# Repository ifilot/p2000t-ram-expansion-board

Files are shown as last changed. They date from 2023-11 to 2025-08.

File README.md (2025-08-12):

# P2000T RAM expansion board







## Table of contents

* [Purpose](#purpose)
* [Memory lay-out](#memory-lay-out)
* [Installation](#installation)
* [Testing the expansion board](#testing-the-expansion-board)
* [Schematic](#schematic)
* [Bill of materials](#bill-of-materials)
* [Testing bank switching in BASIC](#testing-bank-switching-in-basic)
* [Files](#files)
* [Alternative RAM expansions](#alternative-ram-expansions)
  * [SMD-128KiB version](#smd-128kib-version)
  * [SMD-CPLD-128KiB version](#smd-cpld-128kib-version)
  * [SMD-CPLD-512KiB version](#smd-cpld-512kib-version)
  * [THT-1056 KiB expansion](#tht-1056-kib-expansion)
  * [THT-2080 KiB expansion](#tht-2080-kib-expansion)
* [License](#license)

> [!TIP] 
> Have questions or comments about the **P2000T RAM expansion**? Join
> the conversation and chat with the developers on our [Discord
> server](https://discord.gg/YtzJTWYAxy).

## Purpose

This repository provides several RAM expansion boards for the Philips P2000T,
ranging from 64 KiB to over 2 MiB. Options vary in complexity (THT, SMD, CPLD),
so choose a board that fits your soldering skills and tools. A RAM tester
utility is included to verify proper installation and functionality after
assembly.

> [!IMPORTANT]
> This repository includes various RAM expansion PCBs for the P2000T. Your
> choice should depend on your soldering skills (THT or SMD) and available
> tools (e.g. CPLD programmer). Review this README to find a board that
> matches your comfort level before starting a build. 

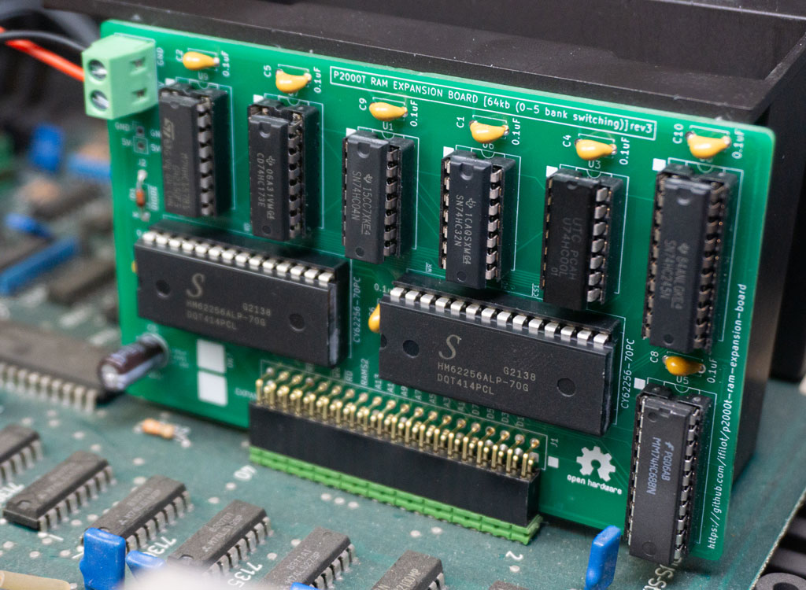
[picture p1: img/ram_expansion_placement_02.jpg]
ram expansion board


## Memory lay-out

The memory lay-out of the P2000T is organized as shown in the table below

| Address | Description |
| --- | --- |
| 0x0000-0x1000 | Monitor rom |
| 0x1000-0x4FFF | Cartridge |
| 0x5000-0x5FFF | Video memory |
| 0x6000-0x9FFF | RAM memory |
| 0xA000-0xDFFF | 16 KiB expansion |
| 0xE000-0xFFFF | 8 KiB banks |

For the default 16 KiB stock model, only the memory at `0x6000-0x9FFF` is
available. The most simple expansion board adds 64k memory such that an
additional 16 KiB of RAM is available at `0xA000-0xDFFF` and another 48 KiB
using bank switching. Bank switching means that you can only access 8 KiB of the
48 KiB at a time, depending on the value of a register which can be accessed via
an `OUT` instruction at `0x94`. This register can hold values of `0-5`,
amounting to 6x8 KiB = 48 KiB of bankable memory.

## Installation

To install the expansion board, you need to plug in the expansion board on the
corresponding expansion 2x20 male pin header on the male board. This pin header
is found directly behind the cartridge slots. Furthermore, you need to solder
a GND and a 5V line onto the power PCB (see image below) and insert that in the
screw terminal of the expansion board.

> [!WARNING]  
> Please check carefully that the polarity is correct. Although the board comes
> with reverse polarity protection in the form of a diode, it is always better
> to check twice before turning on the power.

In the image below, you see a GND (black) and a 5V (red) line attached to the
power PCB. Please ensure you solder the lines to the correct pins and check
with a multimeter before connecting to the RAM expansion board.

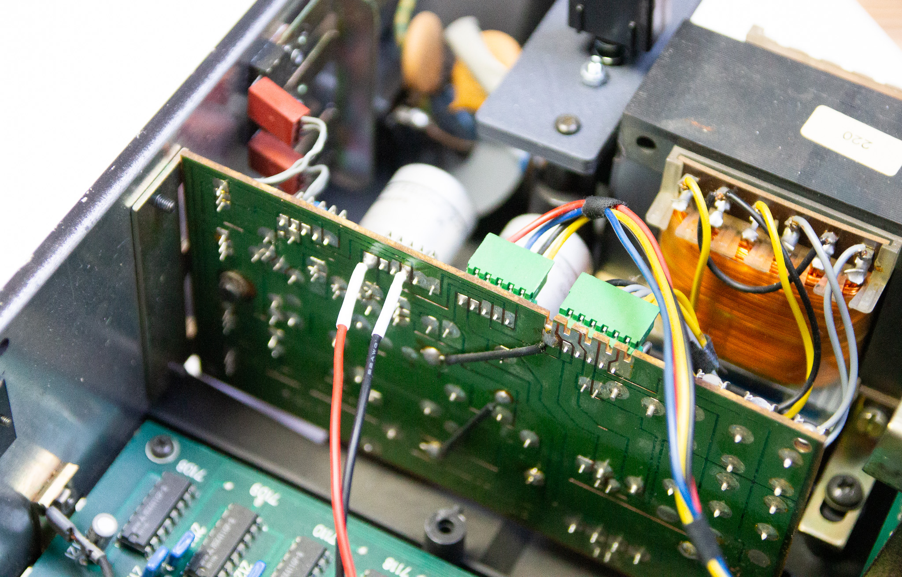
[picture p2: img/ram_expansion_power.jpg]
attaching GND and 5V wire to power PCB


Consult the image below for the correct voltages between the pins.

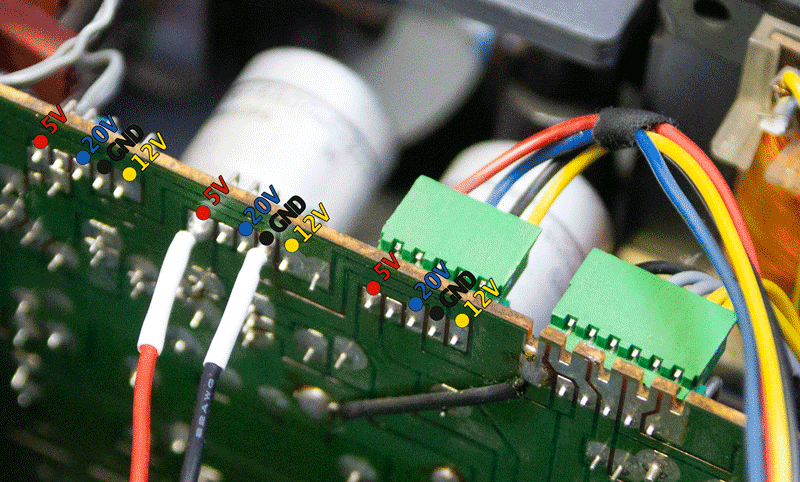
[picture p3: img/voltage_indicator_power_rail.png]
voltages on the power PCB


> [!WARNING]  
> Please check with a multimeter that you did not short-circuit any of the power
> lines on the POWER PCB. Please check this at least two times before turning on
> your P2000T. Short-circuiting of any of the power rails can cause permanent
> damage your machine.

## Testing the expansion board

This repository comes bundled with a RAM testing utility. Write the RAM testing
utility to a SLOT1 cartridge and boot your P2000T with this program in SLOT1.
The RAM testing utility will perform an extensive test of the memory and show
any errors it encounters.

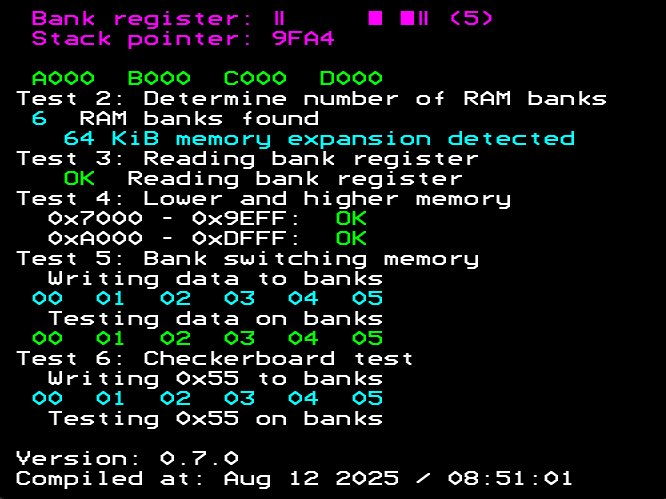
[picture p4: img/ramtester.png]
completed RAM test


## Schematic

The schematic for the RAM expansion board is shown below. The ram expansion
board essentially hosts two 32 KiB RAM chips and a bank register. Using a small
set of additional logic chips, the line decoding and bank switching is handled.

voltages on the power PCB

## Bill of materials

* 1x74HC00 (quad NAND-gate)
* 1x74HC04 (hex inverter)
* 1x74HC32 (quad OR-gate)
* 1x74HC157 (quad 2-input multiplexer)
* 1x74HC173 (quad positive edge triggered D-type flip-flop)
* 1x74HC688 (8-bit magnitude comparator)
* 1x74HC245 (octal bus transceiver)
* 2x62256 (32 KiB SRAM)
* 1x220uF capacitor (100uF also works)
* 8x0.1uF capacitor
* 1x1N4148 diode
* 1x 40 pin female pin header (2x20 pins; 2.54mm spacing)
* 1x screw terminal

**Unpopulated PCB**

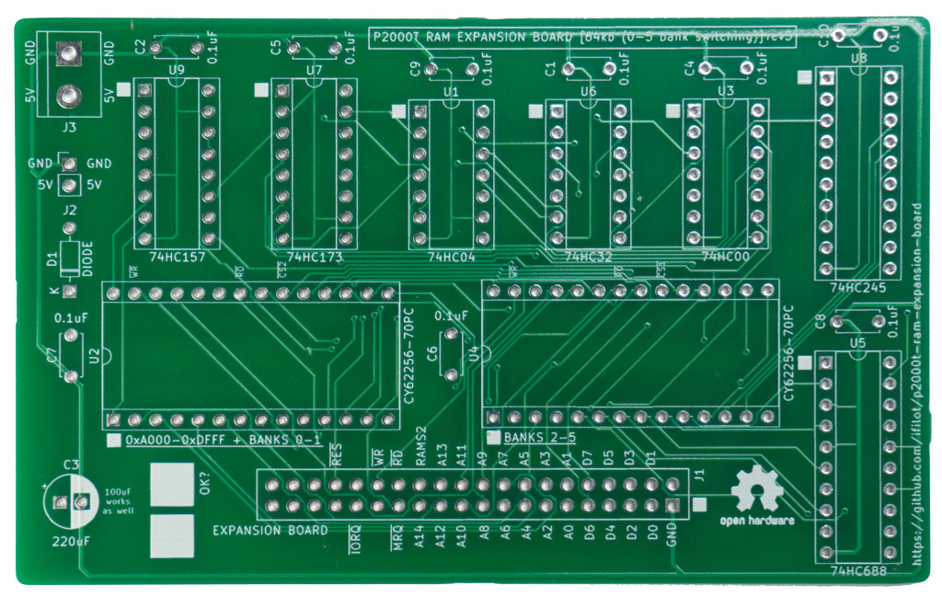
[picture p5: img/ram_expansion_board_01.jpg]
Unpopulated RAM board


**Populated PCB**

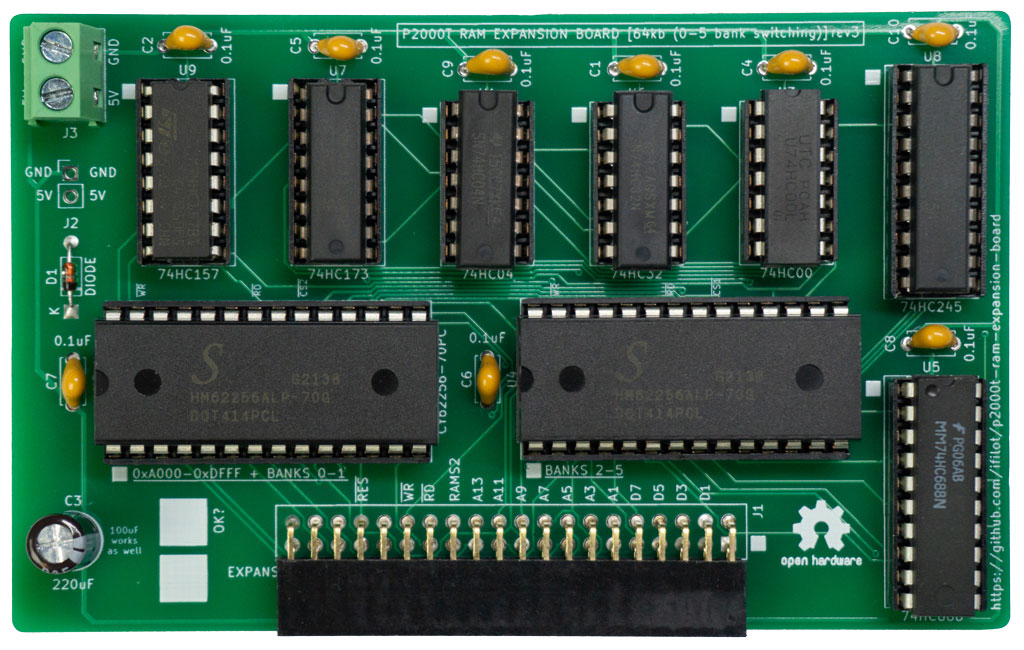
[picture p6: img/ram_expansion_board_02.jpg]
Populated RAM board


## Testing bank switching in BASIC

If you want to test the bank switching functionality in BASIC, you can use
the following instructions after booting the machine.

First, we need to set the top of BASIC to `0x9000`.

```
CLEAR 50,&H9000
```

The reason we do this is to ensure that the stack is not residing at the top 8
KiB because those bytes will become inaccessible after bank switching. Next, we
will first write a value to memory address `0xE000`, check that this value is
properly written, change to another bank and read from the same memory address.
A different value should be returned (typically 0). Next, we write a different
value to the `0xE000` and change bank to the initial bank. The original value
should now be correctly retrieved. The procedure is performed using the
following (very small) snippet of BASIC code.

```
10 POKE &HE000,42
20 PRINT(PEEK(&HE000))
30 OUT &H94,1
40 PRINT(PEEK(&HE000))
50 POKE &HE000,43
60 OUT &H94,0
70 PRINT(PEEK(&HE000))
```
After entering in these instructions, type `RUN`. The output of this code should
be something similar to the code as shown below. The second value might be
potentially different, depending on earlier memory operations, though is
expected to be a zero on a fresh boot of the machine.

```
42
0
42
```

## Files

* [KiCad schematics](pcb/p2000t-ram-expansion-board)
* [RAM tester utility](ramtester)

## Alternative RAM expansions

### SMD-128KiB version

Next to the 64 KiB memory expansion using
[DIP](https://en.wikipedia.org/wiki/Dual_in-line_package) chips, there is also a
128 KiB memory expansion using
[SMD](https://en.wikipedia.org/wiki/Surface-mount_technology) chips. Because of
the typical lower price of this last category of chips, this memory expansion is
a bit cheaper to produce. It does require you to be proficient in soldering on
SMD components.

The 128 KiB memory expansion uses a single `CY62128ELL-45SX` 128 KiB memory
chip. The lower 16 KiB of this chip can be accessed at `0xA000-0xDFFF`. The
remaining 112 KiB are available as 14 banks of 8 KiB each at `0xE000-0xFFFF`.
Similar to the other memory expansion boards, bank switching proceeds by writing
a value to I/O port `0x94`. One can also read back the current bank from this
port.

The source files for this board can be found
[here](pcb/p2000t-ram-expansion-board-128kb-smd/).

**Unpopulated PCB**

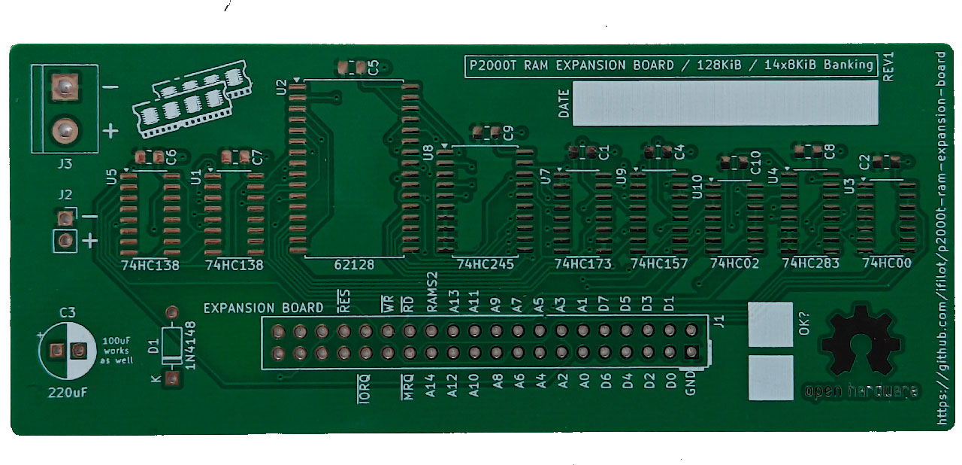
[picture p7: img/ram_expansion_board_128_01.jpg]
Unpopulated RAM board


**Populated PCB**

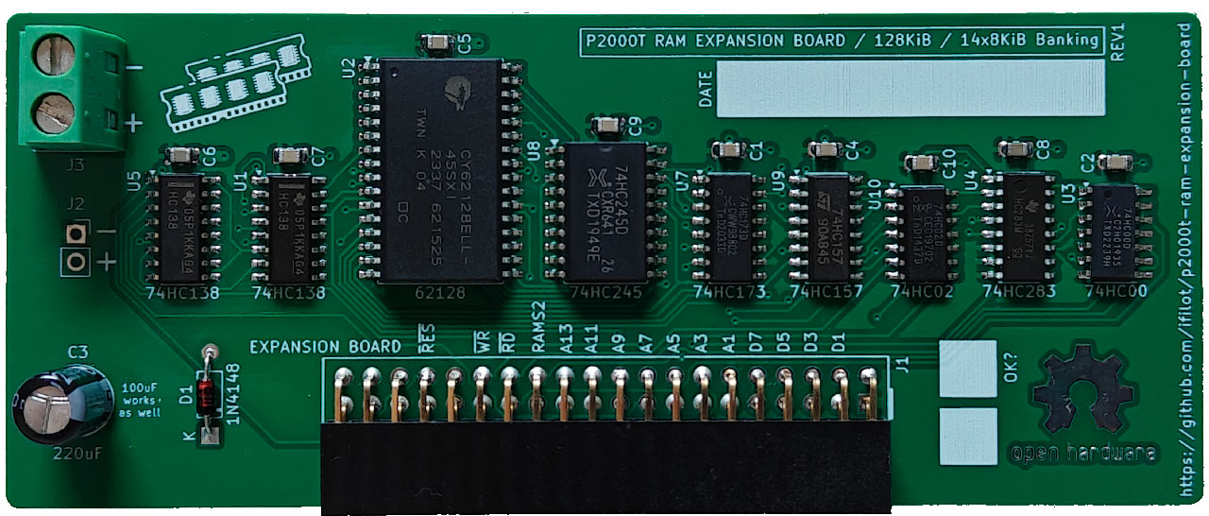
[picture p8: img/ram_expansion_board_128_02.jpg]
Populated RAM board


**Installed PCB**

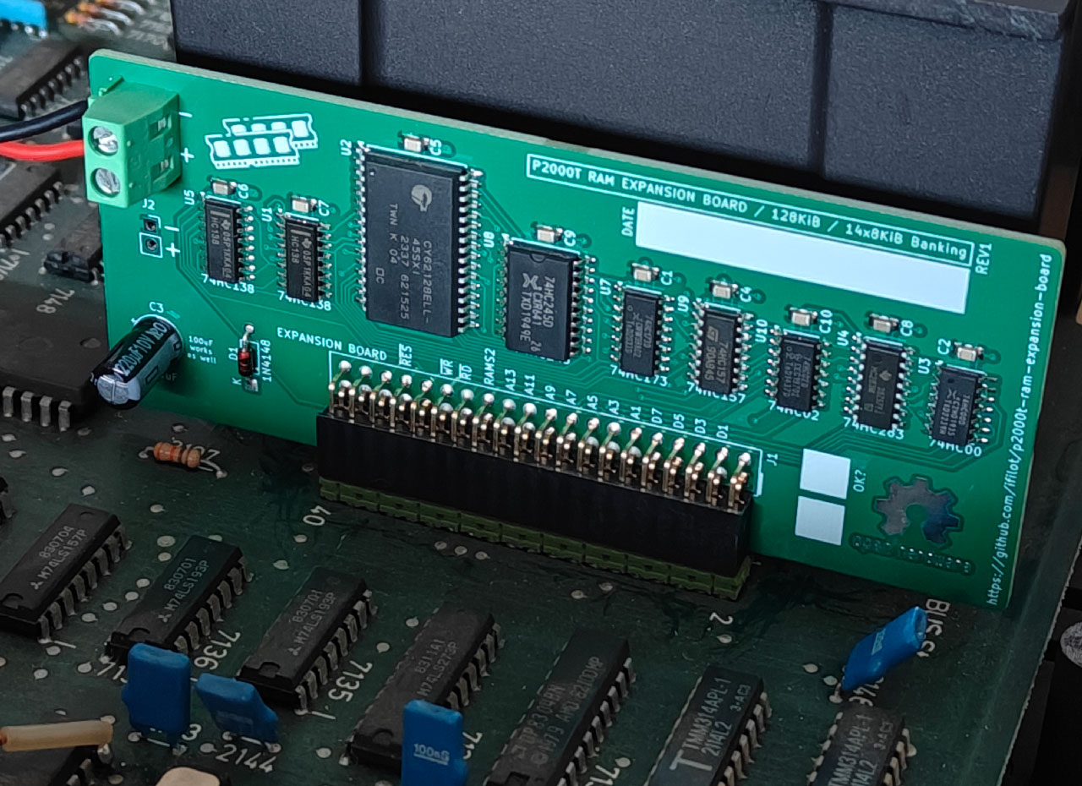
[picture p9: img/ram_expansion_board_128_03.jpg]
Installed 1056 KiB RAM board


### SMD-CPLD-128KiB version

To cut down costs even further, there is also a CUPL version. Besides the
`CY62128ELL-45SX`, the PCB only hosts one other chip: a `ATF1502`. All glue
logic required for the RAM expansion board is basically programmed on this chip.

The source files for this board can be found
[here](pcb/p2000t-ram-expansion-board-128-512-smd-cpld).

**Unpopulated PCB**

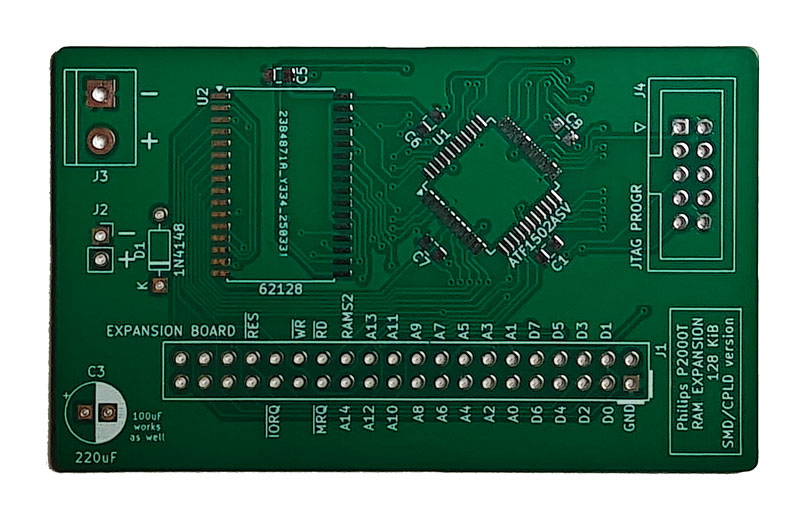
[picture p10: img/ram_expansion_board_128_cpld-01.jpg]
Unpopulated RAM board


**Populated PCB**

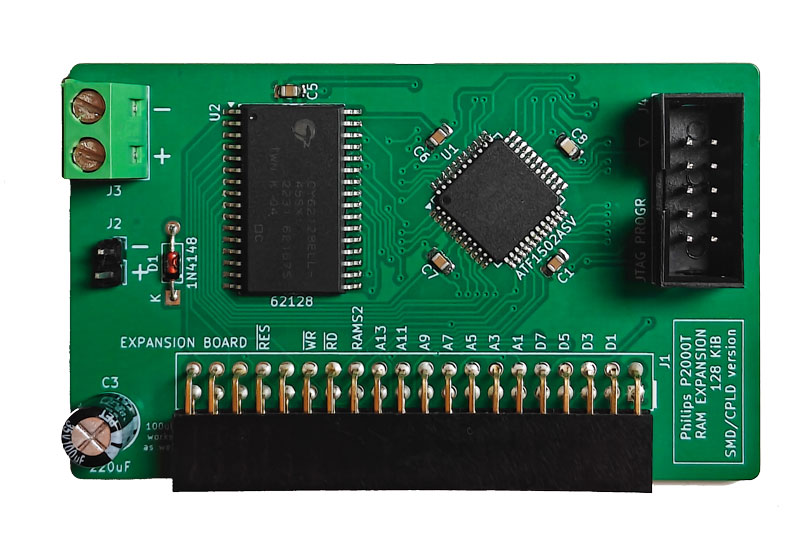
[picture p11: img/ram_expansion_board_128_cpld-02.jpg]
Populated RAM board


### SMD-CPLD-512KiB version

Moving beyond the 128 KiB limit, there is also a versatile SMD-type board
that admits 1-4 `CY62128ELL-45SX` 128 KiB memory chips.

The source files for this board can be found
[here](pcb/p2000t-ram-expansion-board-128-512-smd-cpld).

**Installed PCB**

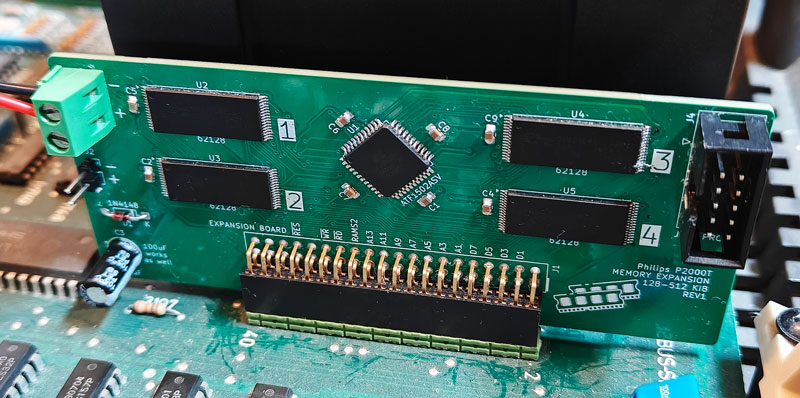
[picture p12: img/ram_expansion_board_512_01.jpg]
Installed RAM board


**Populated PCB**

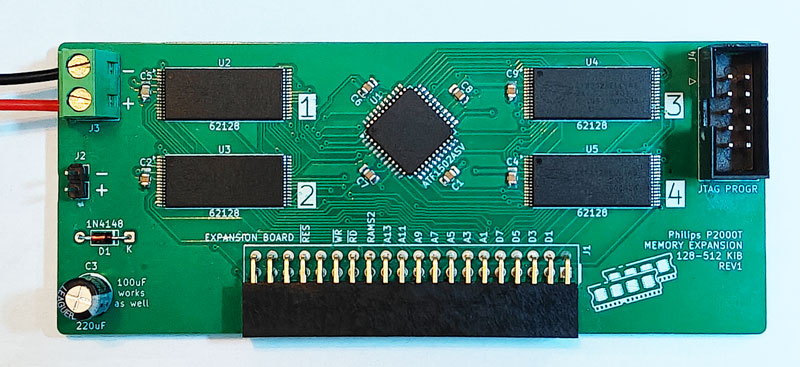
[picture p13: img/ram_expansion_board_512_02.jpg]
Populated RAM board


### THT-1056 KiB expansion

This board uses a single 32 KiB static RAM chip to provide 2x16 KiB on
`0xA000-0xDFFF` and two 512 KiB static RAM chips to provide another 128x8 KiB on
`0xE000-0xFFFF`. The way this board works is very similar to the regular 64 KiB
board. The highest bit in the bank register toggle the 16 KiB banking while the
lower 7 bits provide the banking for the 8 KiB of memory.

The source files for this board can be found
[here](pcb/p2000t-ram-expansion-board-1056kb/).

**Unpopulated PCB**

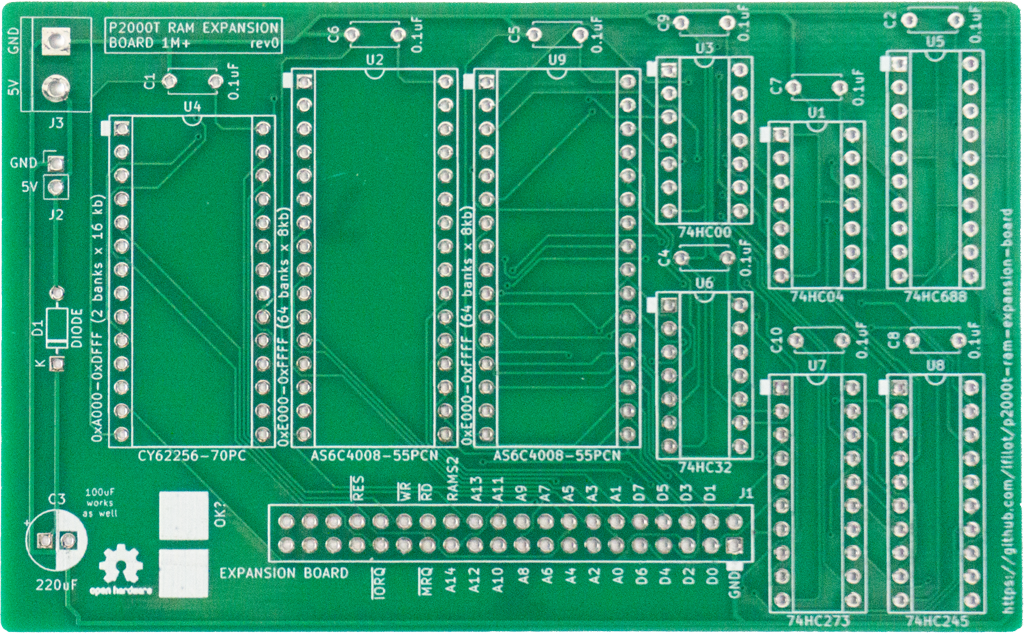
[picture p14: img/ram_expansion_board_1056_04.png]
Unpopulated RAM board


**Populated PCB**

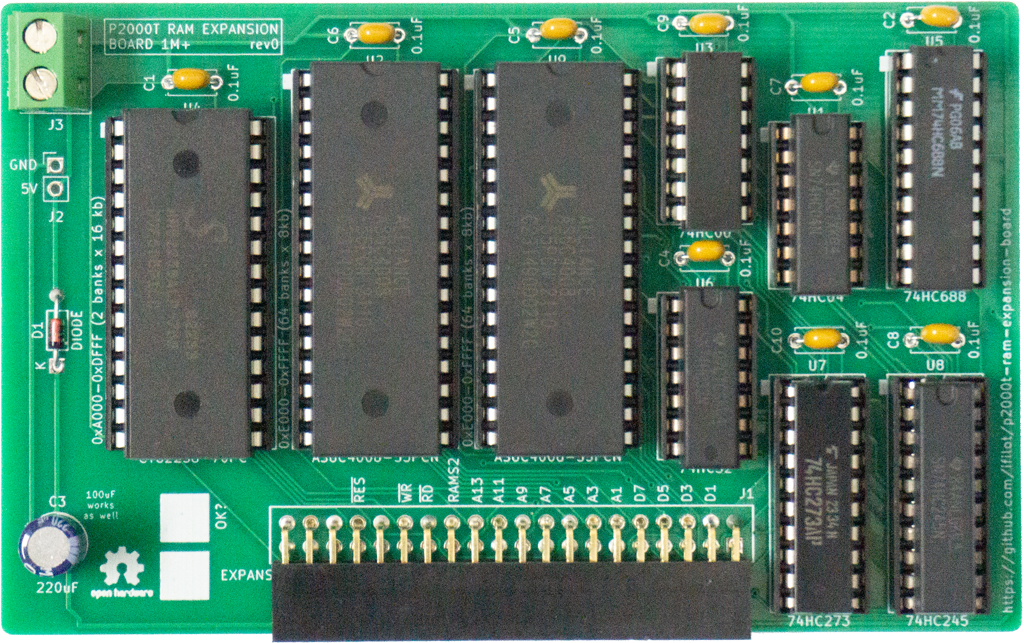
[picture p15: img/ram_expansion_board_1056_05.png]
Populated RAM board


**Installed PCB**

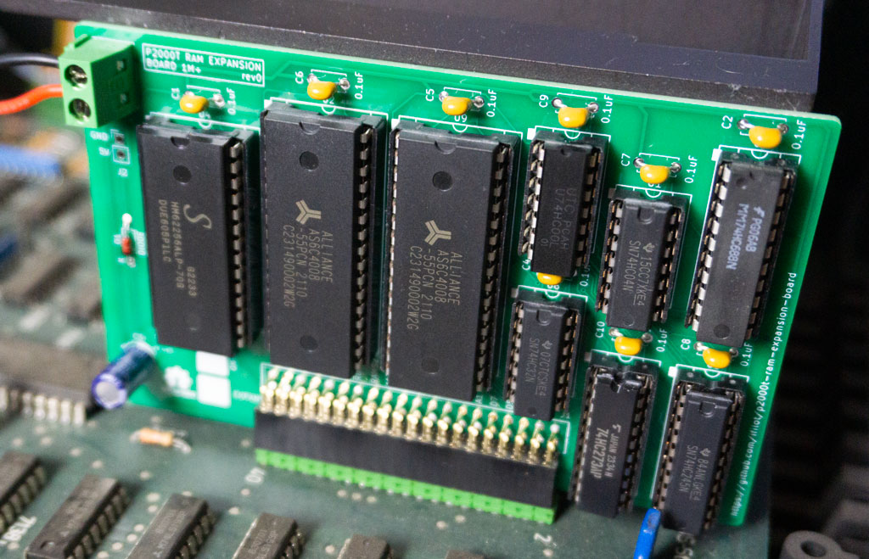
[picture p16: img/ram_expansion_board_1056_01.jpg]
Installed 1056 KiB RAM board


### THT-2080 KiB expansion

This board uses a single 32 KiB static RAM chip to provide 2x16 KiB on
`0xA000-0xDFFF` and four 512 KiB static RAM chips to provide another 256x8 KiB
on `0xE000-0xFFFF`. This board requires two bank registers, one 8-bit bank
register exposed on I/O port `0x94` and another two-bit bank register on I/O
port `0x95` (only one bit of the two-bit bank register is used).

The source files for this board can be found
[here](pcb/p2000t-ram-expansion-board-2080kb/).

**Populated PCB**

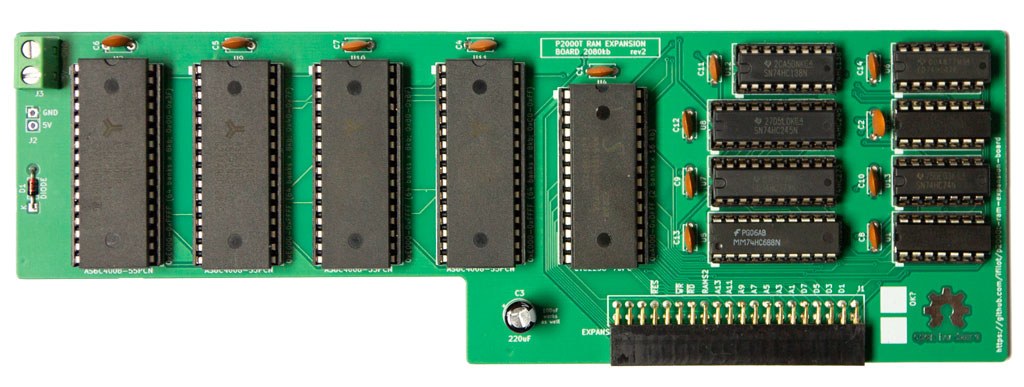
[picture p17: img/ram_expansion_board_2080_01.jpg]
Populated RAM board


**Installed PCB**

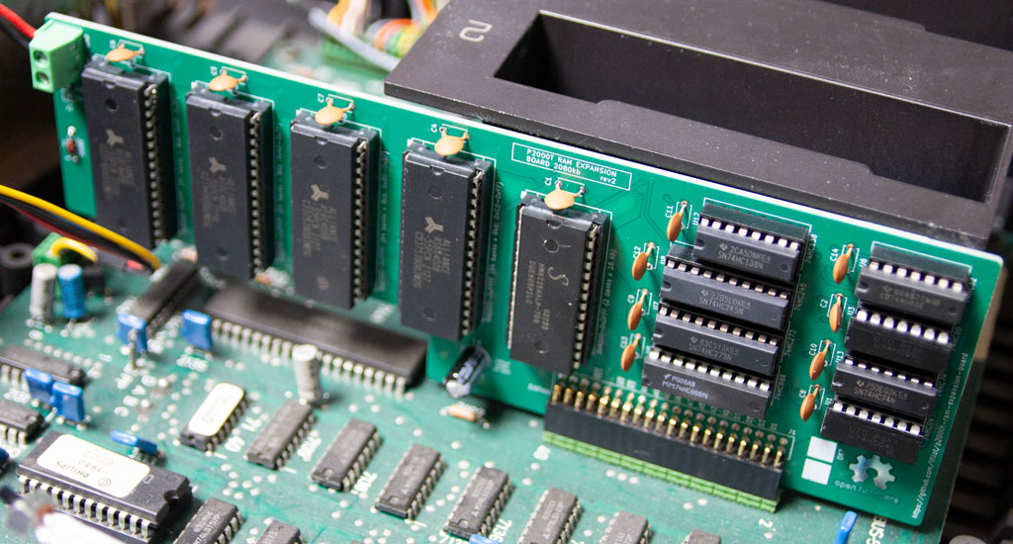
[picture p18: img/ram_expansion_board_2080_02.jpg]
Installed 2080 KiB RAM board


## License

* All source code, i.e. the [ram tester utility](ramtester)
  are released under a [GPLv3 license](https://www.gnu.org/licenses/gpl-3.0.html).
* The hardware files (KiCad schematics) are released under the 
  [CC BY-SA 4.0](https://creativecommons.org/licenses/by-sa/4.0/) license.

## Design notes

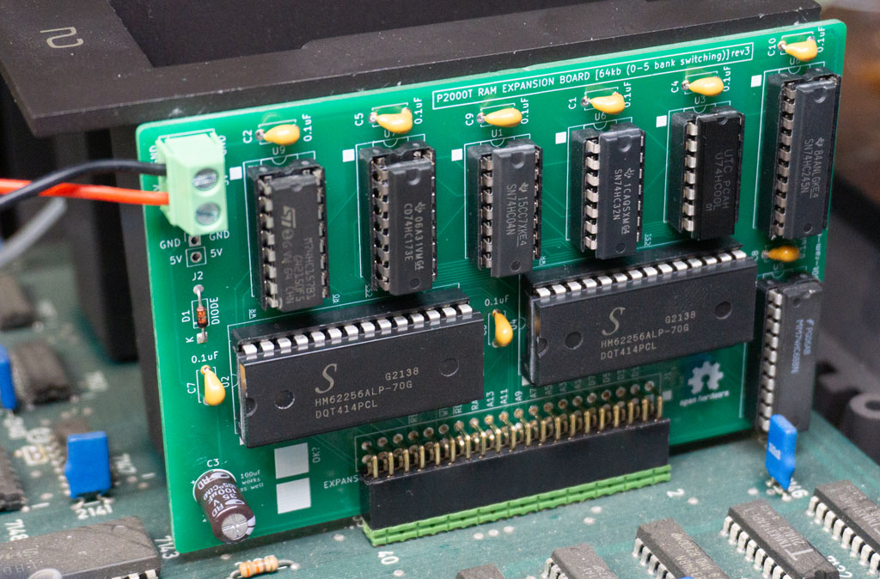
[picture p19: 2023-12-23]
img/ram_expansion_placement_01.jpg

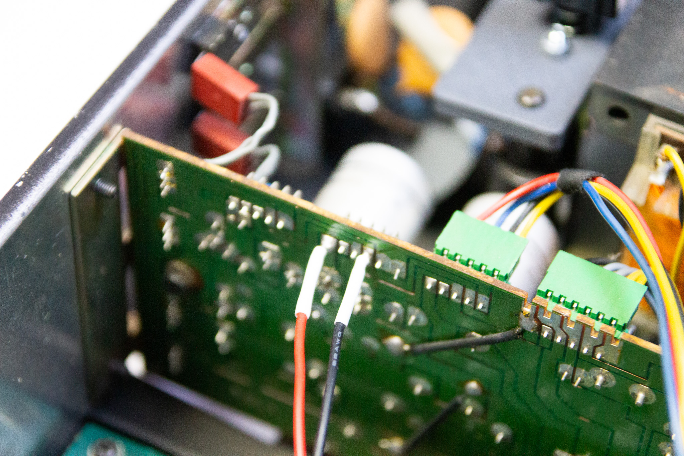
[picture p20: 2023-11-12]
img/ram_expansion_power_02.jpg

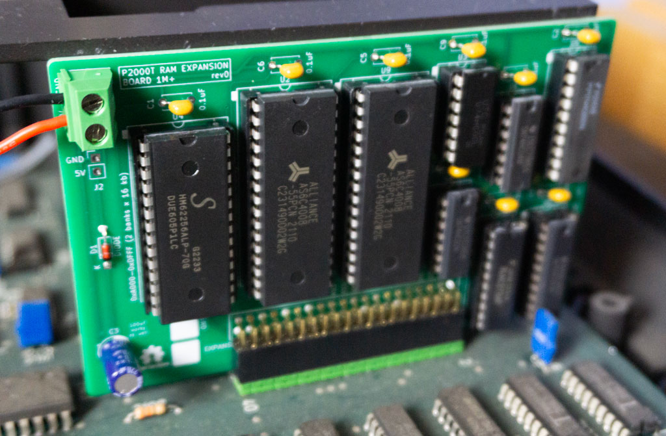
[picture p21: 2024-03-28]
img/ram_expansion_board_1056_02.jpg

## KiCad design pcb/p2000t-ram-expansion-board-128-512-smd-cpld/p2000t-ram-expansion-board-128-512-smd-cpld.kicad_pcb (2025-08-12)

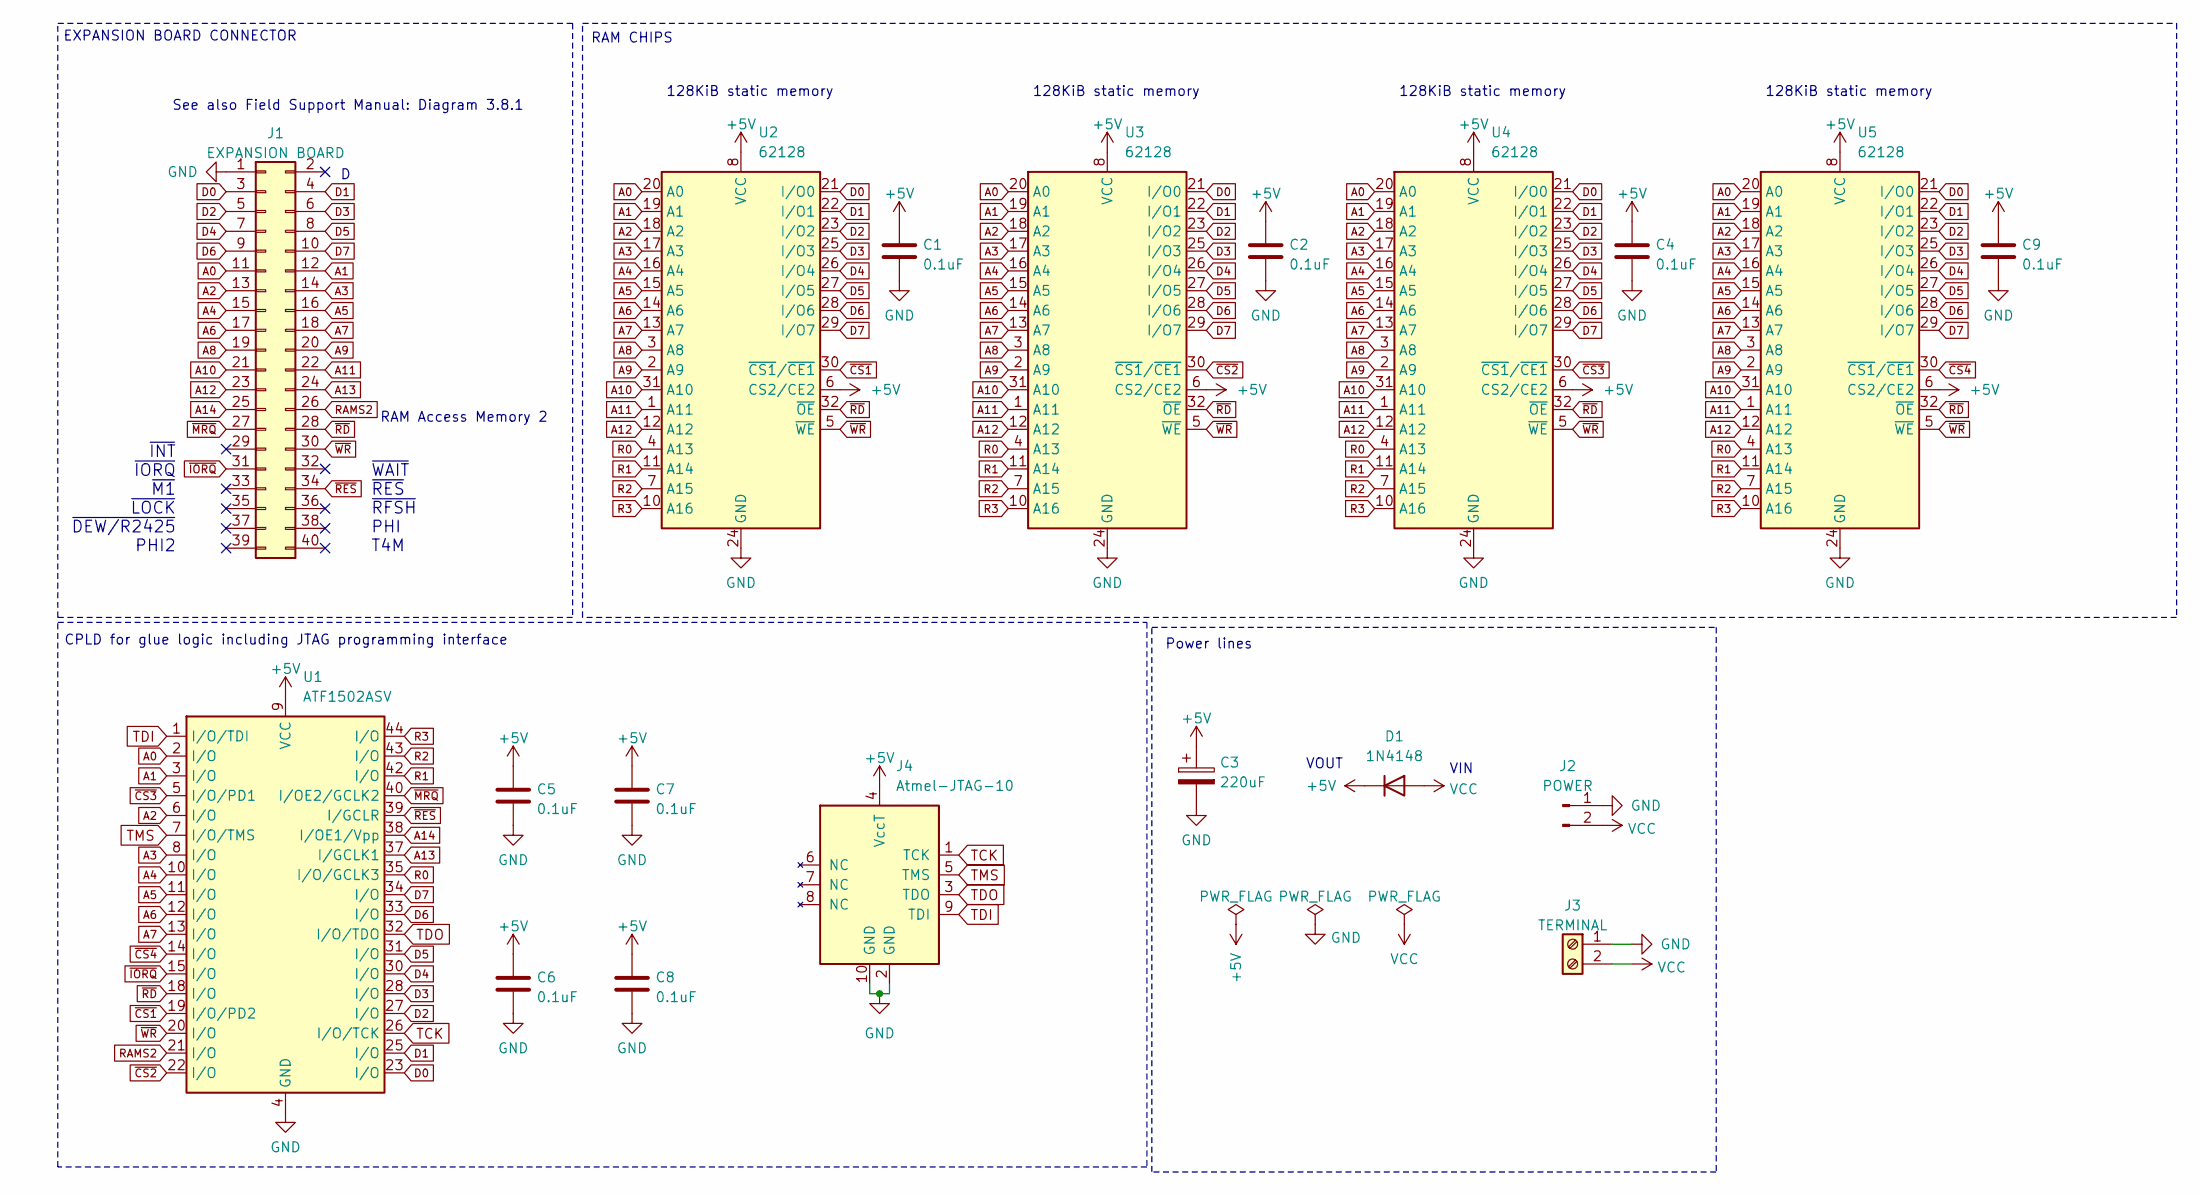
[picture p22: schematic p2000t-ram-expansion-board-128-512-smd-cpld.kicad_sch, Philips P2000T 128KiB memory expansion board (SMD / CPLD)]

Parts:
C1, C2, C4, C5, C6, C7, C8, C9: 0.1uF; C_0805_2012Metric_Pad1.18x1.45mm_HandSolder; LCSC Part # C126469
C3: 220uF; CP_Radial_D6.3mm_P2.50mm
D1: 1N4148; D_DO-35_SOD27_P7.62mm_Horizontal
J1: EXPANSION BOARD; PinHeader_2x20_P2.54mm_Vertical
J2: POWER; PinSocket_1x02_P2.54mm_Vertical
J3: TERMINAL; TerminalBlock_bornier-2_P5.08mm
J4: Atmel-JTAG-10; IDC-Header_2x05_P2.54mm_Vertical
U1: ATF1502ASV; TQFP-44_10x10mm_P0.8mm
U2, U3, U4, U5: 62128; TSOP-I-32_18.4x8mm_P0.5mm; LCSC Part # C2840304

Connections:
+5V: C1.1, C2.1, C3.1, C4.1, C5.1, C6.1, C7.1, C8.1, C9.1, D1.1 (K), J4.4 (VccT), U1.9 (VCC), U1.17 (VCC), U1.29 (VCC), U1.41 (VCC), U2.6 (CS2/CE2), U2.8 (VCC), U3.6 (CS2/CE2), U3.8 (VCC), U4.6 (CS2/CE2), U4.8 (VCC), U5.6 (CS2/CE2), U5.8 (VCC)
A0: J1.11, U1.2 (I/O), U2.20 (A0), U3.20 (A0), U4.20 (A0), U5.20 (A0)
A1: J1.12, U1.3 (I/O), U2.19 (A1), U3.19 (A1), U4.19 (A1), U5.19 (A1)
A2: J1.13, U1.6 (I/O), U2.18 (A2), U3.18 (A2), U4.18 (A2), U5.18 (A2)
A3: J1.14, U1.8 (I/O), U2.17 (A3), U3.17 (A3), U4.17 (A3), U5.17 (A3)
A4: J1.15, U1.10 (I/O), U2.16 (A4), U3.16 (A4), U4.16 (A4), U5.16 (A4)
A5: J1.16, U1.11 (I/O), U2.15 (A5), U3.15 (A5), U4.15 (A5), U5.15 (A5)
A6: J1.17, U1.12 (I/O), U2.14 (A6), U3.14 (A6), U4.14 (A6), U5.14 (A6)
A7: J1.18, U1.13 (I/O), U2.13 (A7), U3.13 (A7), U4.13 (A7), U5.13 (A7)
A8: J1.19, U2.3 (A8), U3.3 (A8), U4.3 (A8), U5.3 (A8)
A9: J1.20, U2.2 (A9), U3.2 (A9), U4.2 (A9), U5.2 (A9)
A10: J1.21, U2.31 (A10), U3.31 (A10), U4.31 (A10), U5.31 (A10)
A11: J1.22, U2.1 (A11), U3.1 (A11), U4.1 (A11), U5.1 (A11)
A12: J1.23, U2.12 (A12), U3.12 (A12), U4.12 (A12), U5.12 (A12)
A13: J1.24, U1.37 (I/GCLK1)
A14: J1.25, U1.38 (I/OE1/Vpp)
D0: J1.3, U1.23 (I/O), U2.21 (I/O0), U3.21 (I/O0), U4.21 (I/O0), U5.21 (I/O0)
D1: J1.4, U1.25 (I/O), U2.22 (I/O1), U3.22 (I/O1), U4.22 (I/O1), U5.22 (I/O1)
D2: J1.5, U1.27 (I/O), U2.23 (I/O2), U3.23 (I/O2), U4.23 (I/O2), U5.23 (I/O2)
D3: J1.6, U1.28 (I/O), U2.25 (I/O3), U3.25 (I/O3), U4.25 (I/O3), U5.25 (I/O3)
D4: J1.7, U1.30 (I/O), U2.26 (I/O4), U3.26 (I/O4), U4.26 (I/O4), U5.26 (I/O4)
D5: J1.8, U1.31 (I/O), U2.27 (I/O5), U3.27 (I/O5), U4.27 (I/O5), U5.27 (I/O5)
D6: J1.9, U1.33 (I/O), U2.28 (I/O6), U3.28 (I/O6), U4.28 (I/O6), U5.28 (I/O6)
D7: J1.10, U1.34 (I/O), U2.29 (I/O7), U3.29 (I/O7), U4.29 (I/O7), U5.29 (I/O7)
GND: C1.2, C2.2, C3.2, C4.2, C5.2, C6.2, C7.2, C8.2, C9.2, J1.1, J2.1, J3.1, J4.2 (GND), J4.10 (GND), U1.4 (GND), U1.16 (GND), U1.24 (GND), U1.36 (GND), U2.24 (GND), U3.24 (GND), U4.24 (GND), U5.24 (GND)
R0: U1.35 (I/O/GCLK3), U2.4 (A13), U3.4 (A13), U4.4 (A13), U5.4 (A13)
R1: U1.42 (I/O), U2.11 (A14), U3.11 (A14), U4.11 (A14), U5.11 (A14)
R2: U1.43 (I/O), U2.7 (A15), U3.7 (A15), U4.7 (A15), U5.7 (A15)
R3: U1.44 (I/O), U2.10 (A16), U3.10 (A16), U4.10 (A16), U5.10 (A16)
RAMS2: J1.26, U1.21 (I/O)
TCK: J4.1 (TCK), U1.26 (I/O/TCK)
TDI: J4.9 (TDI), U1.1 (I/O/TDI)
TDO: J4.3 (TDO), U1.32 (I/O/TDO)
TMS: J4.5 (TMS), U1.7 (I/O/TMS)
VCC: D1.2 (A), J2.2, J3.2
~CS1: U1.19 (I/O/PD2), U2.30 (~CS1/~CE1)
~CS2: U1.22 (I/O), U3.30 (~CS1/~CE1)
~CS3: U1.5 (I/O/PD1), U4.30 (~CS1/~CE1)
~CS4: U1.14 (I/O), U5.30 (~CS1/~CE1)
~IORQ: J1.31, U1.15 (I/O)
~MRQ: J1.27, U1.40 (I/OE2/GCLK2)
~RD: J1.28, U1.18 (I/O), U2.32 (~OE), U3.32 (~OE), U4.32 (~OE), U5.32 (~OE)
~RES: J1.34, U1.39 (I/GCLR)
~WR: J1.30, U1.20 (I/O), U2.5 (~WE), U3.5 (~WE), U4.5 (~WE), U5.5 (~WE)

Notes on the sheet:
128KiB static memory
VIN
EXPANSION BOARD CONNECTOR
VOUT
~{INT} ~{IORQ} ~{M1} ~{LOCK} ~{DEW/R2425} PHI2
RAM Access Memory 2
RAM CHIPS
See also Field Support Manual: Diagram 3.8.1
Power lines
~{WAIT} ~{RES} ~{RFSH} PHI T4M
CPLD for glue logic including JTAG programming interface

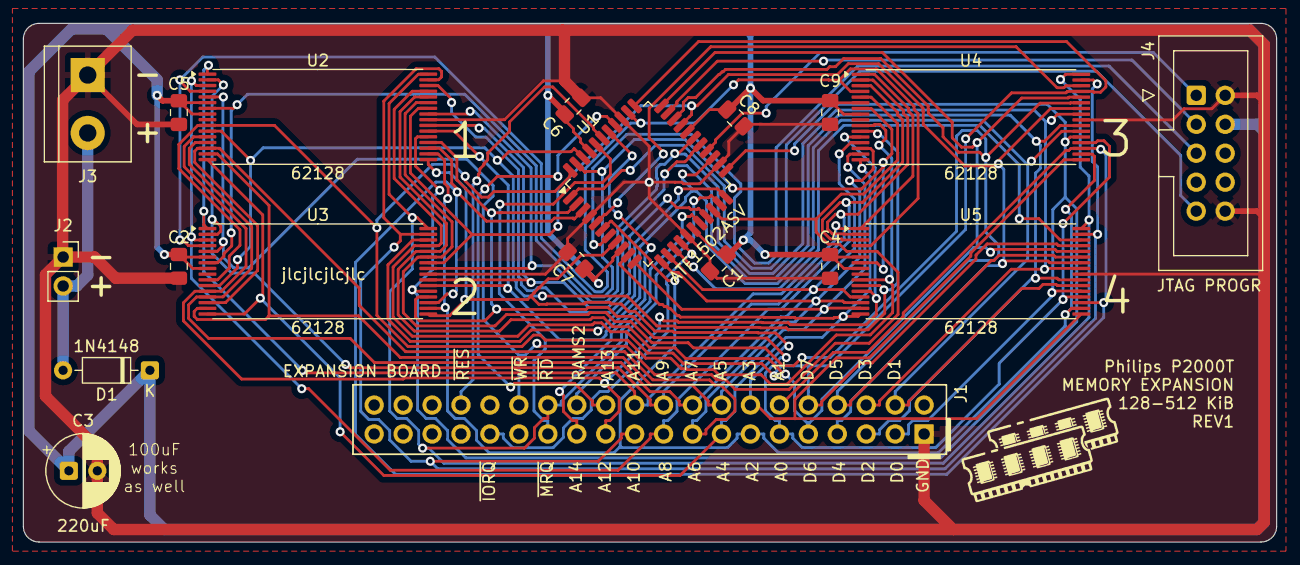
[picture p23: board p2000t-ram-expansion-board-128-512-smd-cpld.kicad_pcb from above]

Board: 2 copper layers, 110.0 x 45.5 mm, 19 parts (1 on the bottom side), 44 nets.

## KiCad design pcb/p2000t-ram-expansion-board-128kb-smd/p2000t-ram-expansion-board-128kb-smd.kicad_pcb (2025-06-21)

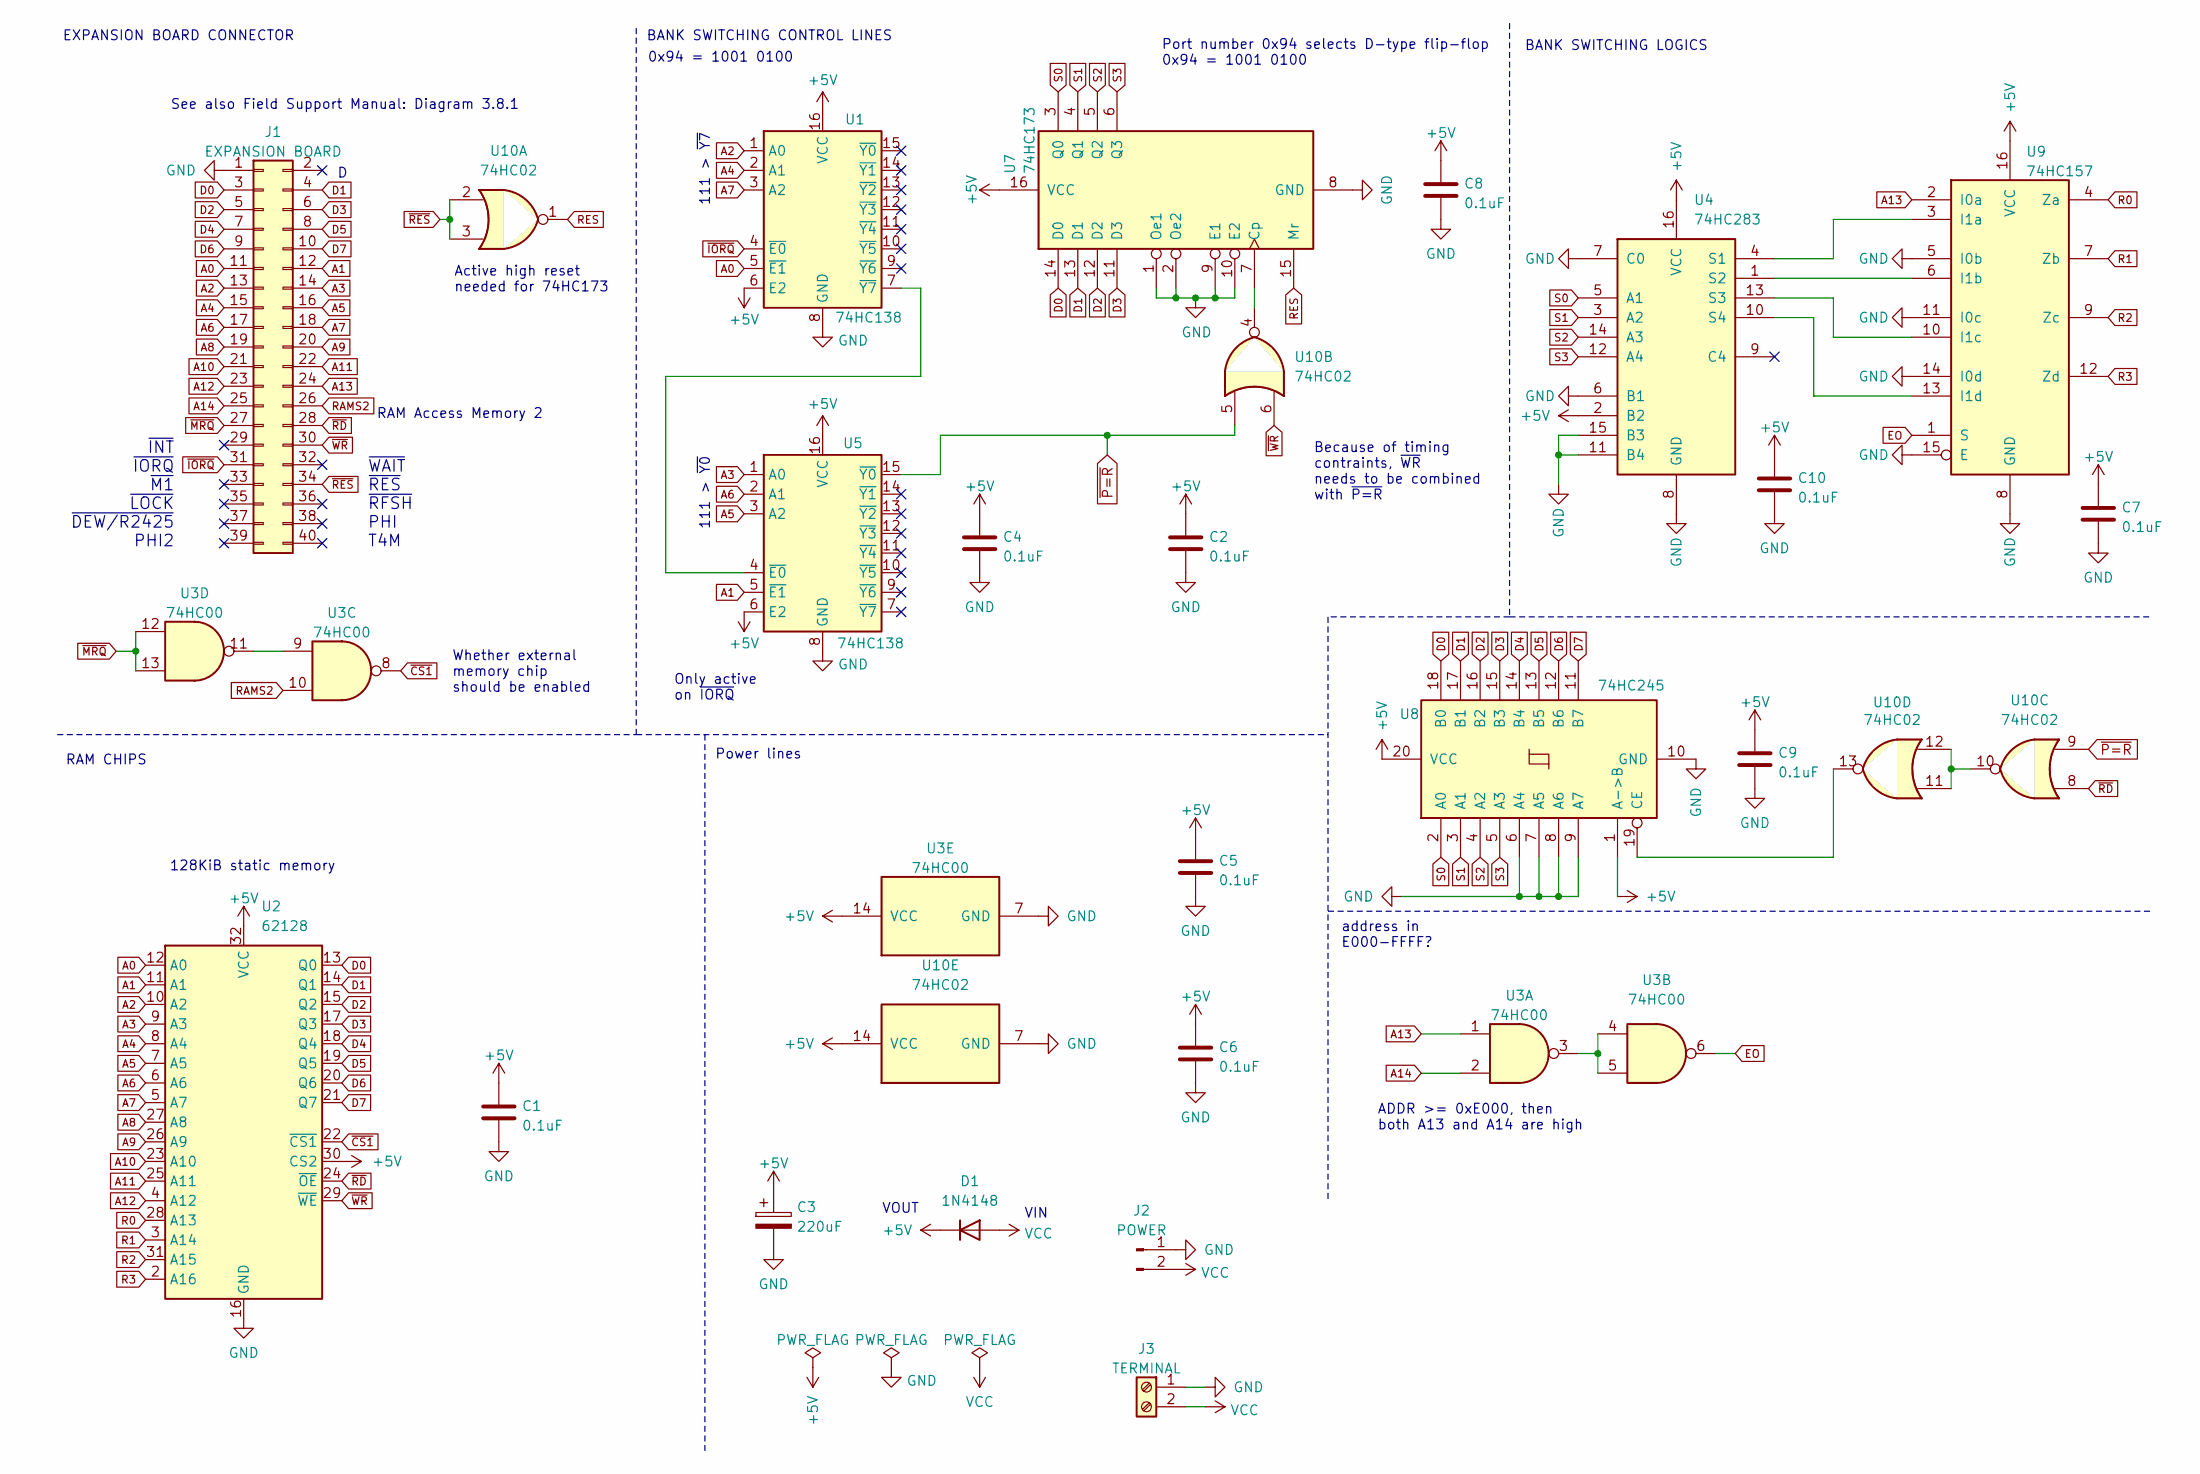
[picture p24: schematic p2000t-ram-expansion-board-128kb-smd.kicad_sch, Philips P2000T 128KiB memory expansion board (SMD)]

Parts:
C1, C2, C4, C5, C6, C7, C8, C9, C10: 0.1uF; C_0805_2012Metric_Pad1.18x1.45mm_HandSolder; LCSC Part # C126469
C3: 220uF; CP_Radial_D6.3mm_P2.50mm
D1: 1N4148; D_DO-35_SOD27_P7.62mm_Horizontal
J1: EXPANSION BOARD; PinHeader_2x20_P2.54mm_Vertical
J2: POWER; PinSocket_1x02_P2.54mm_Vertical
J3: TERMINAL; TerminalBlock_bornier-2_P5.08mm
U1, U5: 74HC138; SOIC-16_3.9x9.9mm_P1.27mm; LCSC Part # C5602
U2: 62128; SSOP-32_11.305x20.495mm_P1.27mm; LCSC Part # C2840304
U3: 74HC00; SOIC-14_3.9x8.7mm_P1.27mm; LCSC Part # C699445
U4: 74HC283; SOIC-16_3.9x9.9mm_P1.27mm; LCSC Part # C543032
U7: 74HC173; SOIC-16_3.9x9.9mm_P1.27mm; LCSC Part # C546651
U8: 74HC245; SOIC-20W_7.5x12.8mm_P1.27mm; LCSC Part # C5625
U9: 74HC157; SOIC-16_3.9x9.9mm_P1.27mm; LCSC Part # C6823
U10: 74HC02; SOIC-14_3.9x8.7mm_P1.27mm; LCSC Part # C5588

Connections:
+5V: C1.1, C2.1, C3.1, C4.1, C5.1, C6.1, C7.1, C8.1, C9.1, C10.1, D1.1 (K), U1.6 (E2), U1.16 (VCC), U2.30 (CS2), U2.32 (VCC), U3.14 (VCC), U4.2 (B2), U4.16 (VCC), U5.6 (E2), U5.16 (VCC), U7.16 (VCC), U8.1 (A->B), U8.20 (VCC), U9.16 (VCC), U10.14 (VCC)
A0: J1.11, U1.5 (~E1), U2.12 (A0)
A1: J1.12, U2.11 (A1), U5.5 (~E1)
A2: J1.13, U1.1 (A0), U2.10 (A2)
A3: J1.14, U2.9 (A3), U5.1 (A0)
A4: J1.15, U1.2 (A1), U2.8 (A4)
A5: J1.16, U2.7 (A5), U5.3 (A2)
A6: J1.17, U2.6 (A6), U5.2 (A1)
A7: J1.18, U1.3 (A2), U2.5 (A7)
A8: J1.19, U2.27 (A8)
A9: J1.20, U2.26 (A9)
A10: J1.21, U2.23 (A10)
A11: J1.22, U2.25 (A11)
A12: J1.23, U2.4 (A12)
A13: J1.24, U3.1, U9.2 (I0a)
A14: J1.25, U3.2
D0: J1.3, U2.13 (Q0), U7.14 (D0), U8.18 (B0)
D1: J1.4, U2.14 (Q1), U7.13 (D1), U8.17 (B1)
D2: J1.5, U2.15 (Q2), U7.12 (D2), U8.16 (B2)
D3: J1.6, U2.17 (Q3), U7.11 (D3), U8.15 (B3)
D4: J1.7, U2.18 (Q4), U8.14 (B4)
D5: J1.8, U2.19 (Q5), U8.13 (B5)
D6: J1.9, U2.20 (Q6), U8.12 (B6)
D7: J1.10, U2.21 (Q7), U8.11 (B7)
EO: U3.6, U9.1 (S)
GND: C1.2, C2.2, C3.2, C4.2, C5.2, C6.2, C7.2, C8.2, C9.2, C10.2, J1.1, J2.1, J3.1, U1.8 (GND), U2.16 (GND), U3.7 (GND), U4.6 (B1), U4.7 (C0), U4.8 (GND), U4.11 (B4), U4.15 (B3), U5.8 (GND), U7.1 (Oe1), U7.2 (Oe2), U7.8 (GND), U7.9 (E1), U7.10 (E2), U8.6 (A4), U8.7 (A5), U8.8 (A6), U8.9 (A7), U8.10 (GND), U9.5 (I0b), U9.8 (GND), U9.11 (I0c), U9.14 (I0d), U9.15 (E), U10.7 (GND)
unnamed: U1.7 (~Y7), U5.4 (~E0)
unnamed: U3.3, U3.4, U3.5
unnamed: U3.9, U3.11
unnamed: U4.4 (S1), U9.3 (I1a)
unnamed: U4.1 (S2), U9.6 (I1b)
unnamed: U4.13 (S3), U9.10 (I1c)
unnamed: U4.10 (S4), U9.13 (I1d)
unnamed: U7.7 (Cp), U10.4
unnamed: U8.19 (CE), U10.13
unnamed: U10.10, U10.11, U10.12
R0: U2.28 (A13), U9.4 (Za)
R1: U2.3 (A14), U9.7 (Zb)
R2: U2.31 (A15), U9.9 (Zc)
R3: U2.2 (A16), U9.12 (Zd)
RAMS2: J1.26, U3.10
RES: U7.15 (Mr), U10.1
S0: U4.5 (A1), U7.3 (Q0), U8.2 (A0)
S1: U4.3 (A2), U7.4 (Q1), U8.3 (A1)
S2: U4.14 (A3), U7.5 (Q2), U8.4 (A2)
S3: U4.12 (A4), U7.6 (Q3), U8.5 (A3)
VCC: D1.2 (A), J2.2, J3.2
~CS1: U2.22 (~CS1), U3.8
~IORQ: J1.31, U1.4 (~E0)
~MRQ: J1.27, U3.12, U3.13
~P=R: U5.15 (~Y0), U10.5, U10.9
~RD: J1.28, U2.24 (~OE), U10.8
~RES: J1.34, U10.2, U10.3
~WR: J1.30, U2.29 (~WE), U10.6

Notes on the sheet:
VIN
EXPANSION BOARD CONNECTOR
VOUT
0x94 = 1001 0100
~{INT} ~{IORQ} ~{M1} ~{LOCK} ~{DEW/R2425} PHI2
Only active on ~{IORQ}
RAM Access Memory 2
111 > ~{Y0}
address in E000-FFFF?
111 > ~{Y7}
Because of timing contraints, ~{WR} needs to be combined with ~{P=R}
BANK SWITCHING LOGICS
RAM CHIPS
See also Field Support Manual: Diagram 3.8.1
Power lines
BANK SWITCHING CONTROL LINES
128KiB static memory
ADDR >= 0xE000, then both A13 and A14 are high
~{WAIT} ~{RES} ~{RFSH} PHI T4M
Active high reset needed for 74HC173
Whether external memory chip should be enabled
Port number 0x94 selects D-type flip-flop 0x94 = 1001 0100

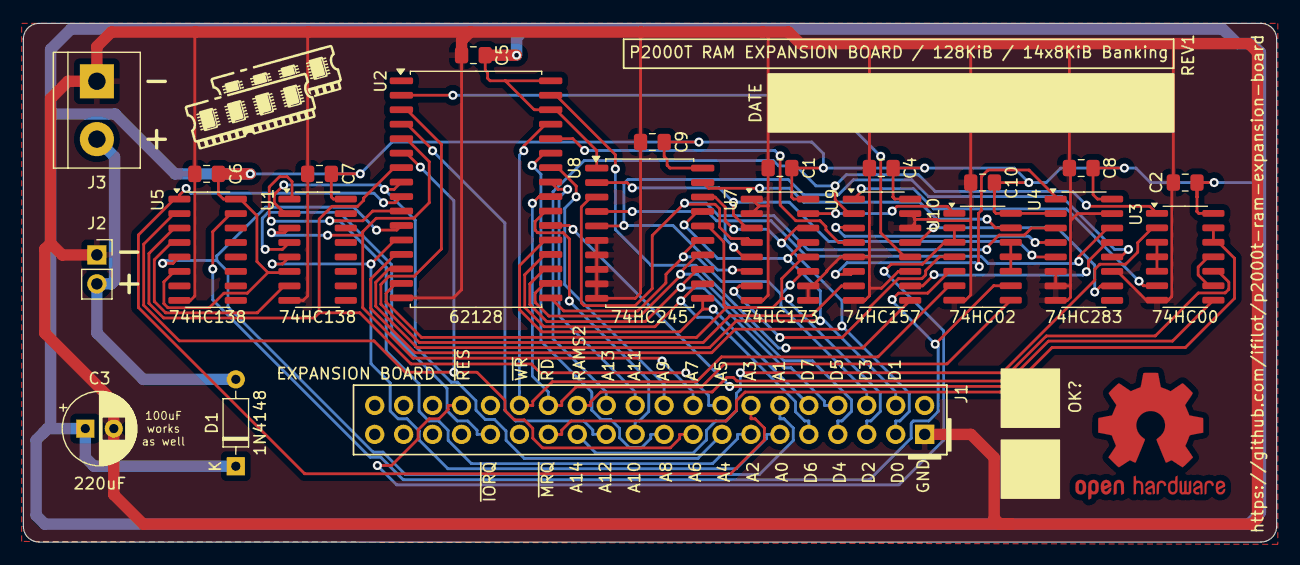
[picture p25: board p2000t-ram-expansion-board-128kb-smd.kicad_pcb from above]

Board: 2 copper layers, 110.0 x 45.5 mm, 24 parts (1 on the bottom side), 54 nets.

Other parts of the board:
LOGO1: OSHW-Logo2_14.6x12mm_Copper_AND_Mask

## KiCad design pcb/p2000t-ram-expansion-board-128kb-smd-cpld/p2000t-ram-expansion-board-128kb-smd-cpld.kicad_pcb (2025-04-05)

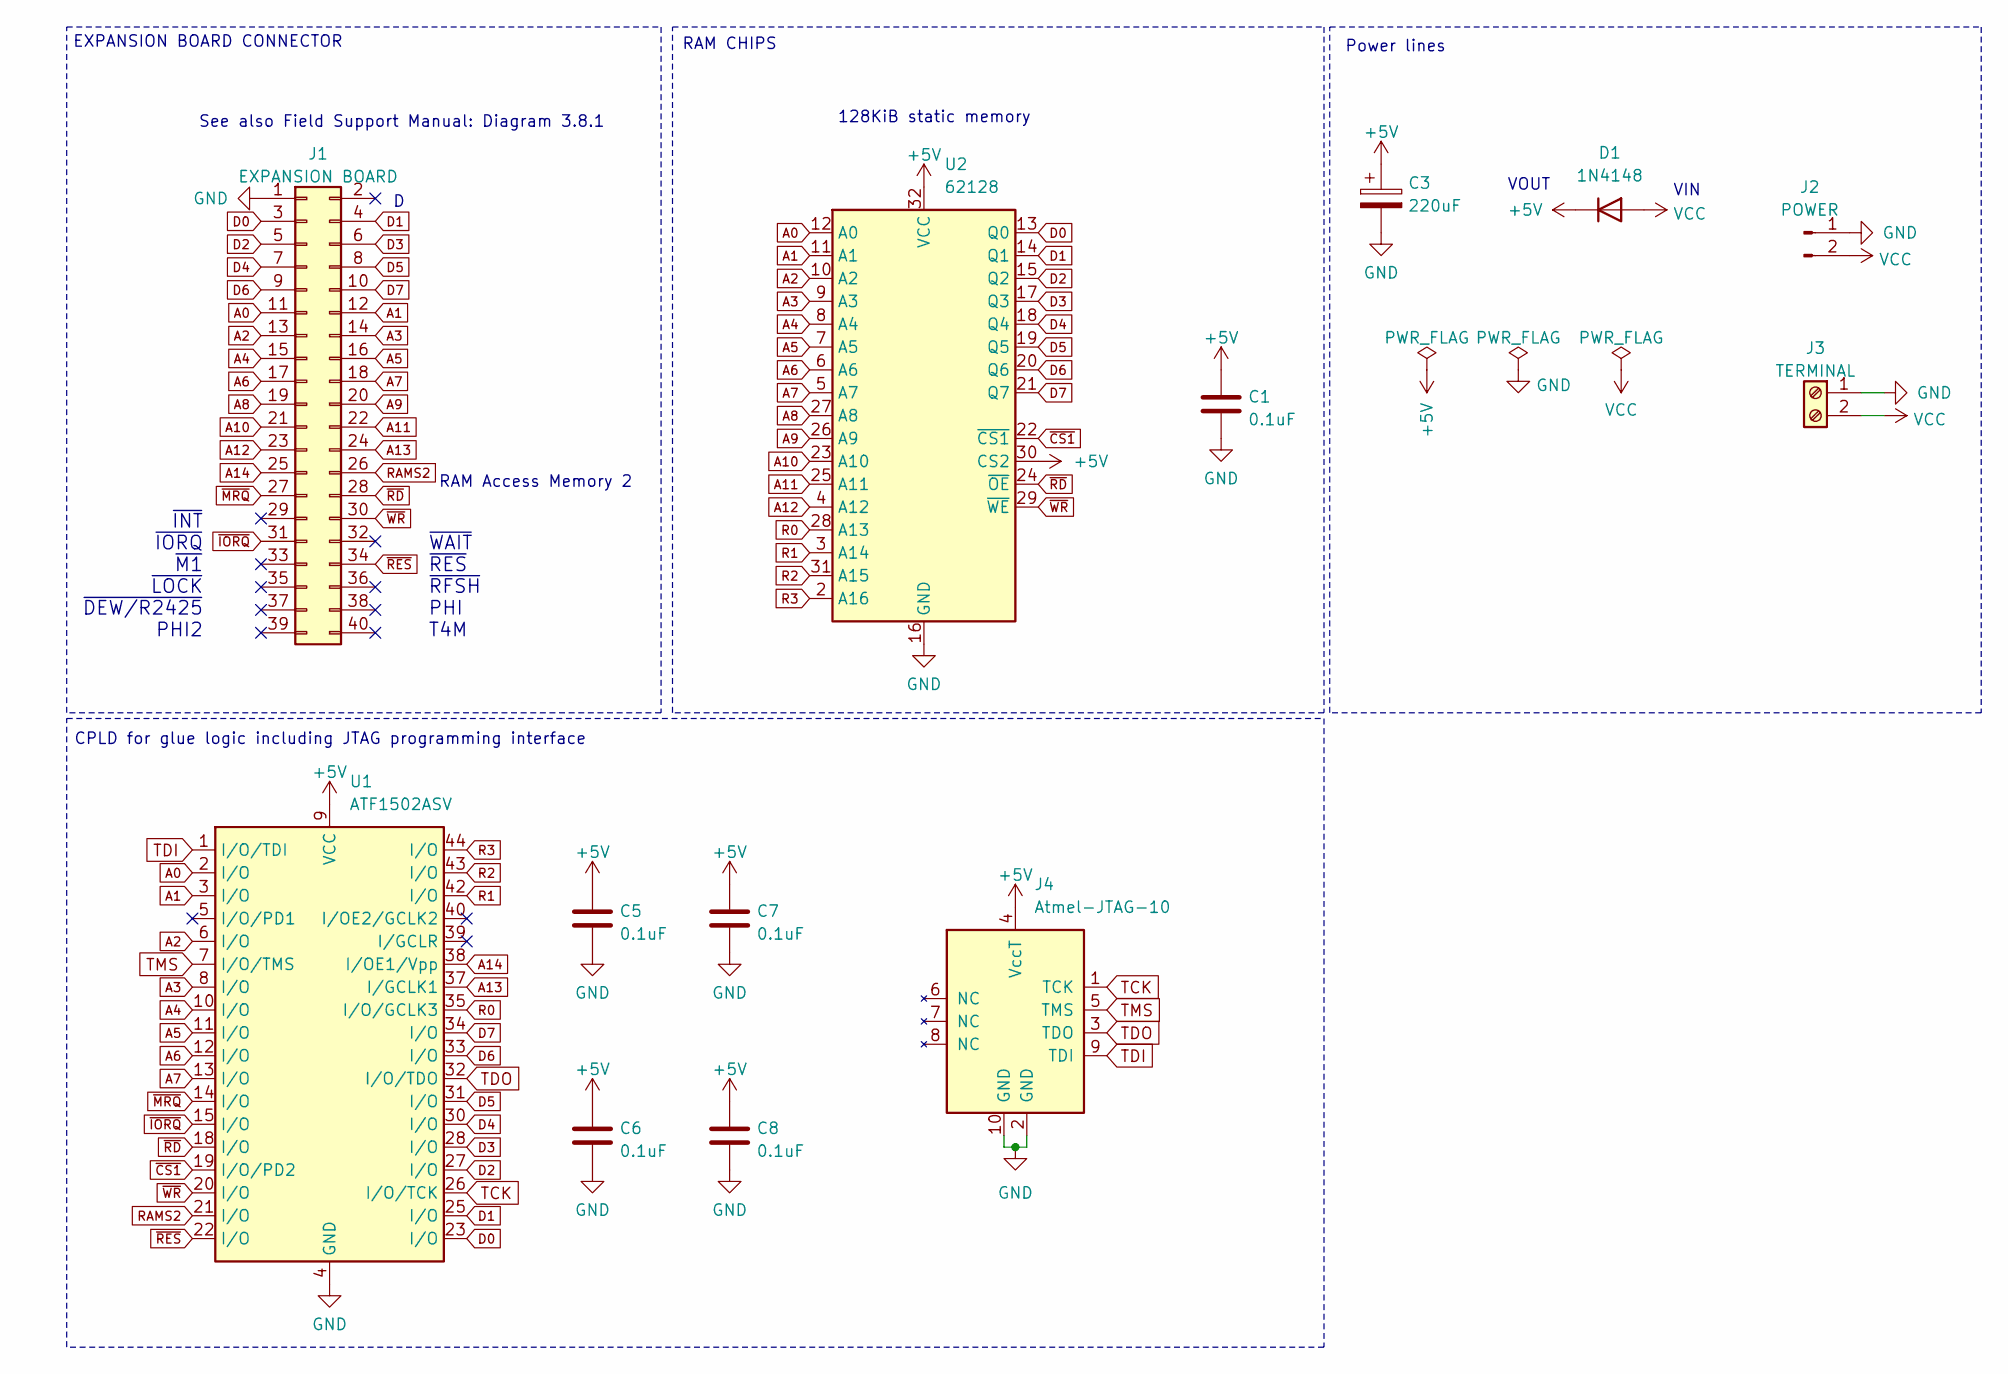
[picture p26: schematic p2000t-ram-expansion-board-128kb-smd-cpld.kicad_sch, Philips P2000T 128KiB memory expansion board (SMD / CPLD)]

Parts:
C1, C5, C6, C7, C8: 0.1uF; C_0805_2012Metric_Pad1.18x1.45mm_HandSolder; LCSC Part # C126469
C3: 220uF; CP_Radial_D6.3mm_P2.50mm
D1: 1N4148; D_DO-35_SOD27_P7.62mm_Horizontal
J1: EXPANSION BOARD; PinHeader_2x20_P2.54mm_Vertical
J2: POWER; PinSocket_1x02_P2.54mm_Vertical
J3: TERMINAL; TerminalBlock_bornier-2_P5.08mm
J4: Atmel-JTAG-10; IDC-Header_2x05_P2.54mm_Vertical
U1: ATF1502ASV; TQFP-44_10x10mm_P0.8mm
U2: 62128; SSOP-32_11.305x20.495mm_P1.27mm; LCSC Part # C2840304

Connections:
+5V: C1.1, C3.1, C5.1, C6.1, C7.1, C8.1, D1.1 (K), J4.4 (VccT), U1.9 (VCC), U1.17 (VCC), U1.29 (VCC), U1.41 (VCC), U2.30 (CS2), U2.32 (VCC)
A0: J1.11, U1.2 (I/O), U2.12 (A0)
A1: J1.12, U1.3 (I/O), U2.11 (A1)
A2: J1.13, U1.6 (I/O), U2.10 (A2)
A3: J1.14, U1.8 (I/O), U2.9 (A3)
A4: J1.15, U1.10 (I/O), U2.8 (A4)
A5: J1.16, U1.11 (I/O), U2.7 (A5)
A6: J1.17, U1.12 (I/O), U2.6 (A6)
A7: J1.18, U1.13 (I/O), U2.5 (A7)
A8: J1.19, U2.27 (A8)
A9: J1.20, U2.26 (A9)
A10: J1.21, U2.23 (A10)
A11: J1.22, U2.25 (A11)
A12: J1.23, U2.4 (A12)
A13: J1.24, U1.37 (I/GCLK1)
A14: J1.25, U1.38 (I/OE1/Vpp)
D0: J1.3, U1.23 (I/O), U2.13 (Q0)
D1: J1.4, U1.25 (I/O), U2.14 (Q1)
D2: J1.5, U1.27 (I/O), U2.15 (Q2)
D3: J1.6, U1.28 (I/O), U2.17 (Q3)
D4: J1.7, U1.30 (I/O), U2.18 (Q4)
D5: J1.8, U1.31 (I/O), U2.19 (Q5)
D6: J1.9, U1.33 (I/O), U2.20 (Q6)
D7: J1.10, U1.34 (I/O), U2.21 (Q7)
GND: C1.2, C3.2, C5.2, C6.2, C7.2, C8.2, J1.1, J2.1, J3.1, J4.2 (GND), J4.10 (GND), U1.4 (GND), U1.16 (GND), U1.24 (GND), U1.36 (GND), U2.16 (GND)
R0: U1.35 (I/O/GCLK3), U2.28 (A13)
R1: U1.42 (I/O), U2.3 (A14)
R2: U1.43 (I/O), U2.31 (A15)
R3: U1.44 (I/O), U2.2 (A16)
RAMS2: J1.26, U1.21 (I/O)
TCK: J4.1 (TCK), U1.26 (I/O/TCK)
TDI: J4.9 (TDI), U1.1 (I/O/TDI)
TDO: J4.3 (TDO), U1.32 (I/O/TDO)
TMS: J4.5 (TMS), U1.7 (I/O/TMS)
VCC: D1.2 (A), J2.2, J3.2
~CS1: U1.19 (I/O/PD2), U2.22 (~CS1)
~IORQ: J1.31, U1.15 (I/O)
~MRQ: J1.27, U1.14 (I/O)
~RD: J1.28, U1.18 (I/O), U2.24 (~OE)
~RES: J1.34, U1.22 (I/O)
~WR: J1.30, U1.20 (I/O), U2.29 (~WE)

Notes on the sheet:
VIN
EXPANSION BOARD CONNECTOR
VOUT
~{INT} ~{IORQ} ~{M1} ~{LOCK} ~{DEW/R2425} PHI2
RAM Access Memory 2
RAM CHIPS
See also Field Support Manual: Diagram 3.8.1
Power lines
128KiB static memory
~{WAIT} ~{RES} ~{RFSH} PHI T4M
CPLD for glue logic including JTAG programming interface

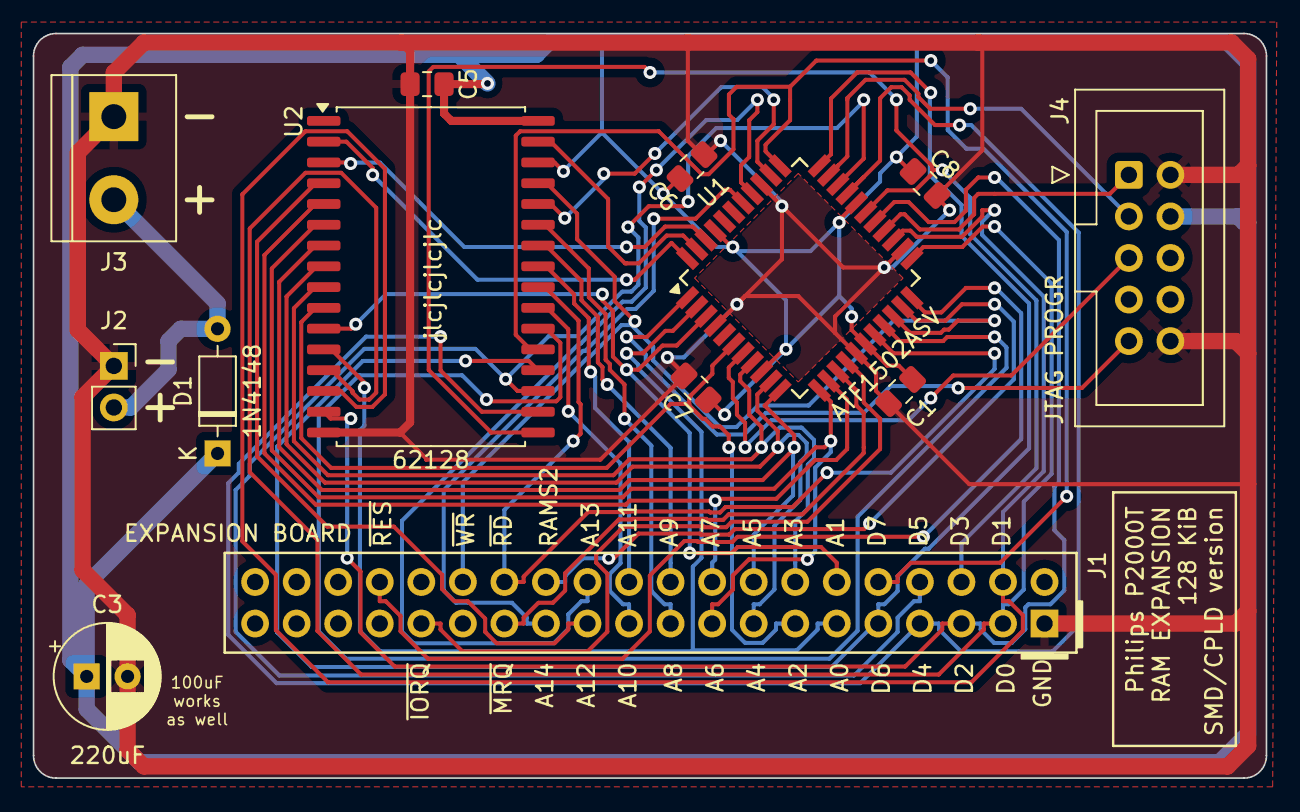
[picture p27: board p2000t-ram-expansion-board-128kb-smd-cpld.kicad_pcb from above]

Board: 2 copper layers, 75.4 x 45.5 mm, 13 parts (1 on the bottom side), 41 nets.

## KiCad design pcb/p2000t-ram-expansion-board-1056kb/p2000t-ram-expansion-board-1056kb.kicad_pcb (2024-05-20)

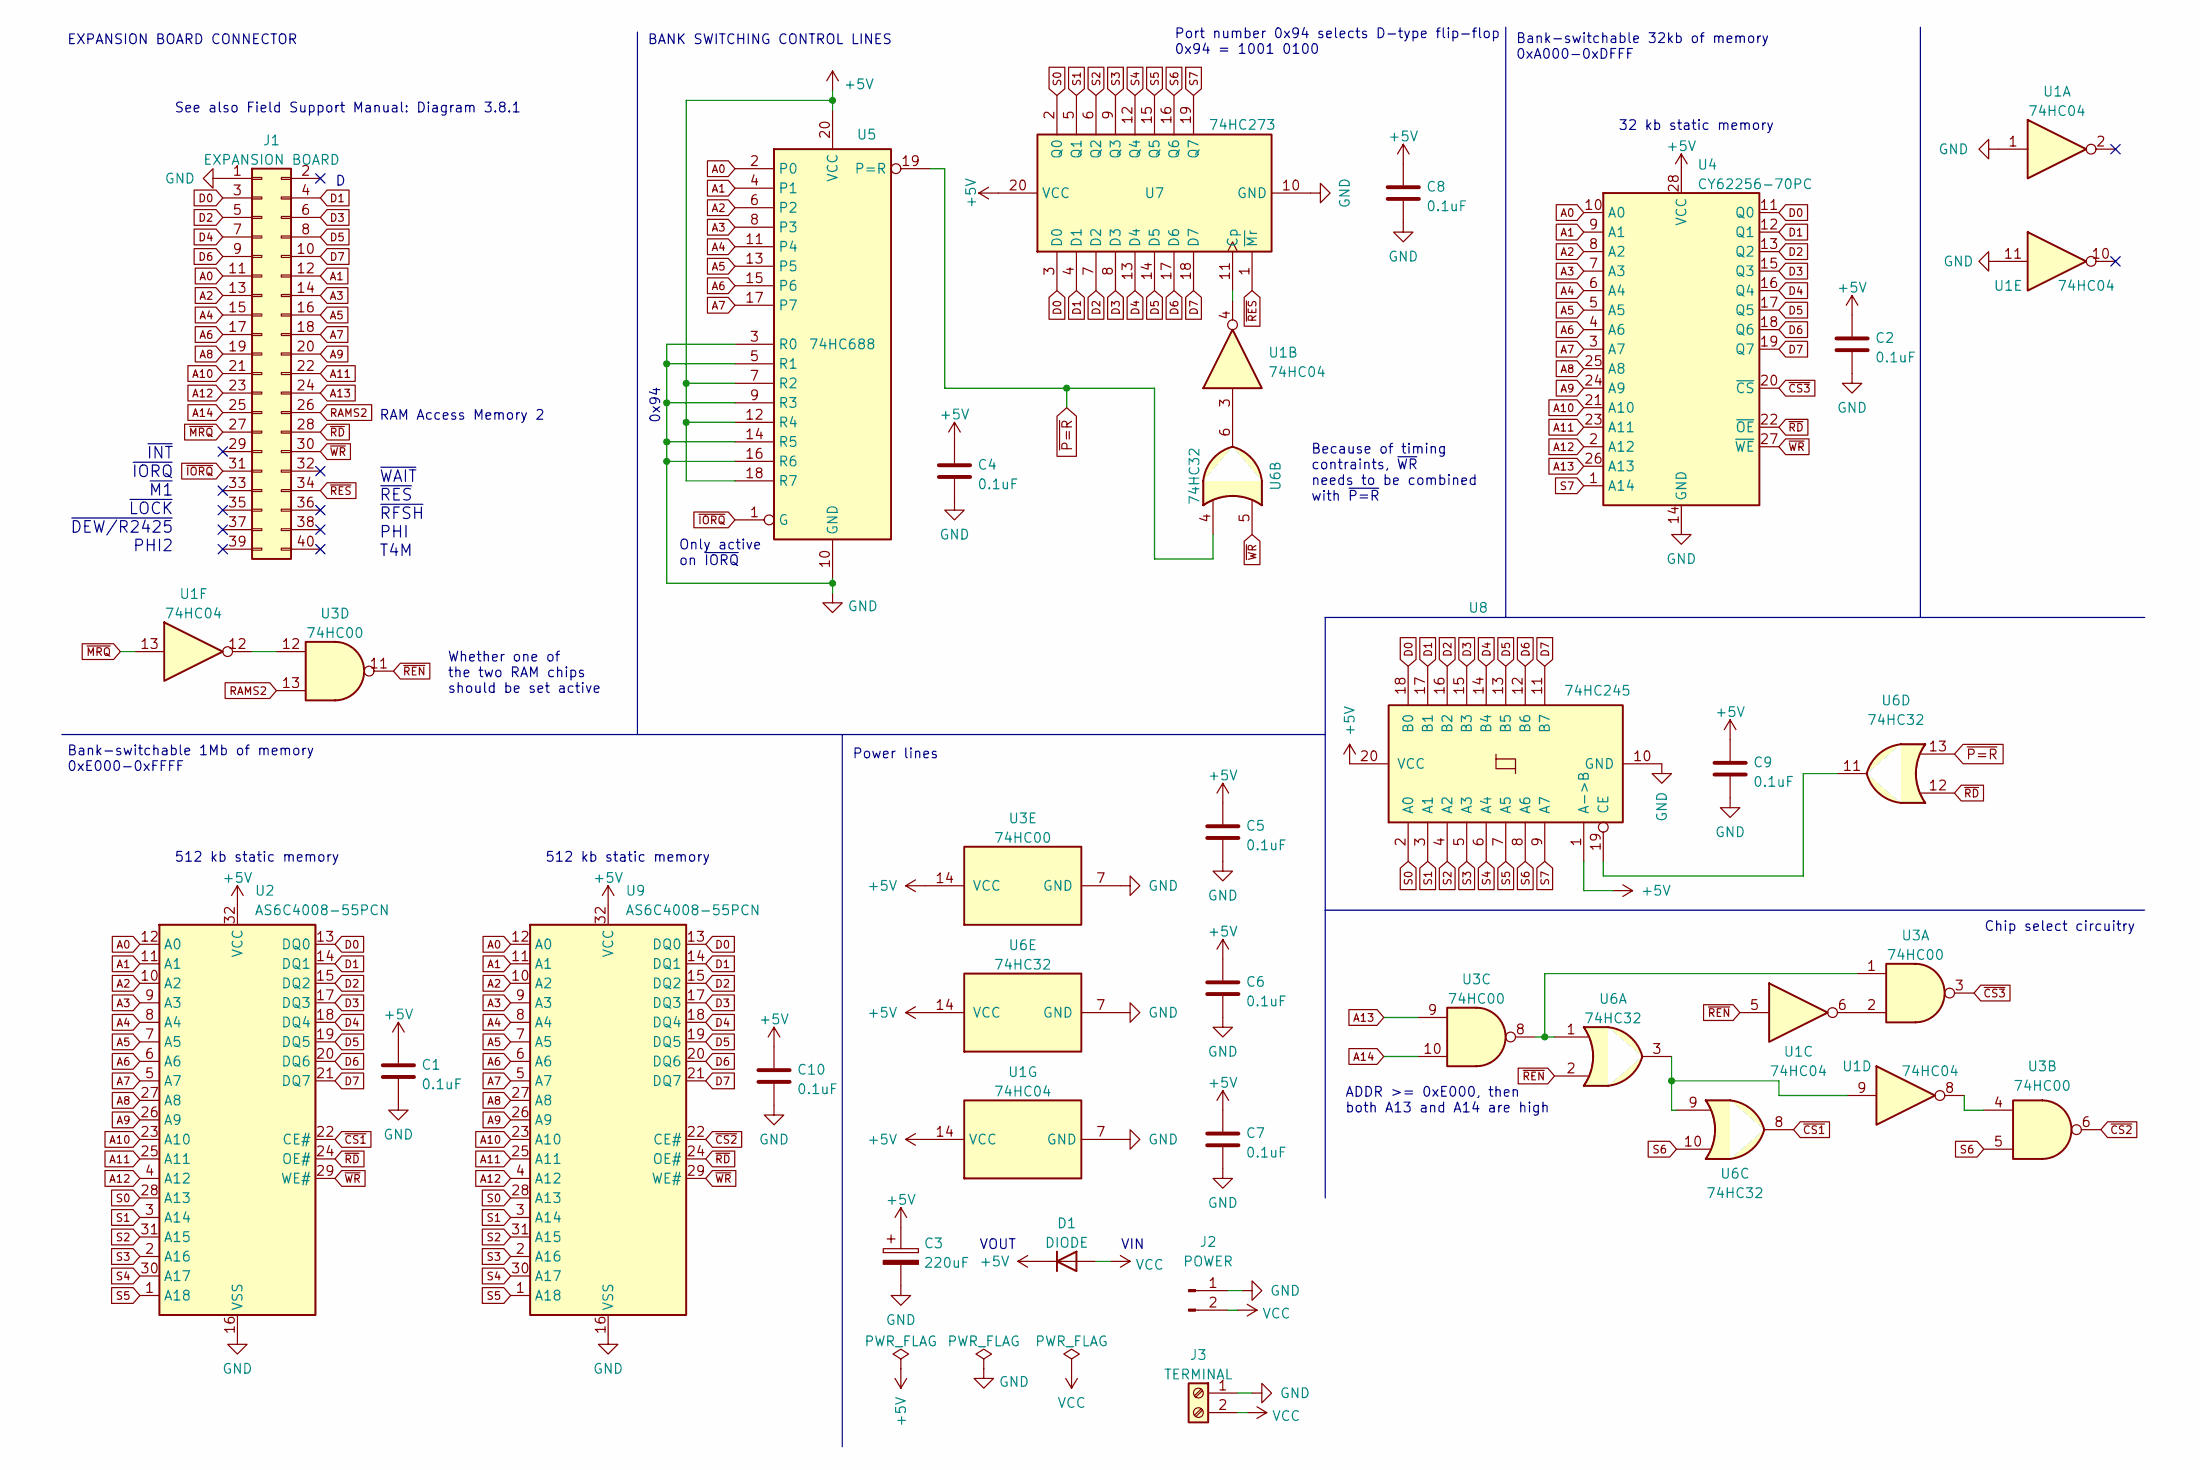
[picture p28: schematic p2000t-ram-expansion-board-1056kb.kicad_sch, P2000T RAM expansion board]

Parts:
C1, C2, C4, C5, C6, C7, C8, C9, C10: 0.1uF; C_Disc_D5.0mm_W2.5mm_P5.00mm
C3: 220uF; CP_Radial_D6.3mm_P2.50mm
D1: DIODE; D_DO-35_SOD27_P7.62mm_Horizontal
J1: EXPANSION BOARD; PinHeader_2x20_P2.54mm_Vertical
J2: POWER; PinHeader_1x02_P2.54mm_Vertical
J3: TERMINAL; TerminalBlock_bornier-2_P5.08mm
U1: 74HC04; DIP-14_W7.62mm_Socket
U2, U9: AS6C4008-55PCN; DIP-32_W15.24mm_Socket
U3: 74HC00; DIP-14_W7.62mm_Socket
U4: CY62256-70PC; DIP-28_W15.24mm_Socket
U5: 74HC688; DIP-20_W7.62mm_Socket
U6: 74HC32; DIP-14_W7.62mm_Socket
U7: 74HC273; DIP-20_W7.62mm_Socket
U8: 74HC245; DIP-20_W7.62mm_Socket

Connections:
+5V: C1.1, C2.1, C3.1, C4.1, C5.1, C6.1, C7.1, C8.1, C9.1, C10.1, D1.1 (K), U1.14 (VCC), U2.32 (VCC), U3.14 (VCC), U4.28 (VCC), U5.7 (R2), U5.12 (R4), U5.18 (R7), U5.20 (VCC), U6.14 (VCC), U7.20 (VCC), U8.1 (A->B), U8.20 (VCC), U9.32 (VCC)
A0: J1.11, U2.12 (A0), U4.10 (A0), U5.2 (P0), U9.12 (A0)
A1: J1.12, U2.11 (A1), U4.9 (A1), U5.4 (P1), U9.11 (A1)
A2: J1.13, U2.10 (A2), U4.8 (A2), U5.6 (P2), U9.10 (A2)
A3: J1.14, U2.9 (A3), U4.7 (A3), U5.8 (P3), U9.9 (A3)
A4: J1.15, U2.8 (A4), U4.6 (A4), U5.11 (P4), U9.8 (A4)
A5: J1.16, U2.7 (A5), U4.5 (A5), U5.13 (P5), U9.7 (A5)
A6: J1.17, U2.6 (A6), U4.4 (A6), U5.15 (P6), U9.6 (A6)
A7: J1.18, U2.5 (A7), U4.3 (A7), U5.17 (P7), U9.5 (A7)
A8: J1.19, U2.27 (A8), U4.25 (A8), U9.27 (A8)
A9: J1.20, U2.26 (A9), U4.24 (A9), U9.26 (A9)
A10: J1.21, U2.23 (A10), U4.21 (A10), U9.23 (A10)
A11: J1.22, U2.25 (A11), U4.23 (A11), U9.25 (A11)
A12: J1.23, U2.4 (A12), U4.2 (A12), U9.4 (A12)
A13: J1.24, U3.9, U4.26 (A13)
A14: J1.25, U3.10
D0: J1.3, U2.13 (DQ0), U4.11 (Q0), U7.3 (D0), U8.18 (B0), U9.13 (DQ0)
D1: J1.4, U2.14 (DQ1), U4.12 (Q1), U7.4 (D1), U8.17 (B1), U9.14 (DQ1)
D2: J1.5, U2.15 (DQ2), U4.13 (Q2), U7.7 (D2), U8.16 (B2), U9.15 (DQ2)
D3: J1.6, U2.17 (DQ3), U4.15 (Q3), U7.8 (D3), U8.15 (B3), U9.17 (DQ3)
D4: J1.7, U2.18 (DQ4), U4.16 (Q4), U7.13 (D4), U8.14 (B4), U9.18 (DQ4)
D5: J1.8, U2.19 (DQ5), U4.17 (Q5), U7.14 (D5), U8.13 (B5), U9.19 (DQ5)
D6: J1.9, U2.20 (DQ6), U4.18 (Q6), U7.17 (D6), U8.12 (B6), U9.20 (DQ6)
D7: J1.10, U2.21 (DQ7), U4.19 (Q7), U7.18 (D7), U8.11 (B7), U9.21 (DQ7)
GND: C1.2, C2.2, C3.2, C4.2, C5.2, C6.2, C7.2, C8.2, C9.2, C10.2, J1.1, J2.1, J3.1, U1.1, U1.7 (GND), U1.11, U2.16 (VSS), U3.7 (GND), U4.14 (GND), U5.3 (R0), U5.5 (R1), U5.9 (R3), U5.10 (GND), U5.14 (R5), U5.16 (R6), U6.7 (GND), U7.10 (GND), U8.10 (GND), U9.16 (VSS)
unnamed: U1.3, U6.6
unnamed: U1.6, U3.2
unnamed: U1.8, U3.4
unnamed: U1.9, U6.3, U6.9
unnamed: U1.12, U3.12
unnamed: U3.1, U3.8, U6.1
unnamed: U1.4, U7.11 (Cp)
unnamed: U6.11, U8.19 (CE)
RAMS2: J1.26, U3.13
S0: U2.28 (A13), U7.2 (Q0), U8.2 (A0), U9.28 (A13)
S1: U2.3 (A14), U7.5 (Q1), U8.3 (A1), U9.3 (A14)
S2: U2.31 (A15), U7.6 (Q2), U8.4 (A2), U9.31 (A15)
S3: U2.2 (A16), U7.9 (Q3), U8.5 (A3), U9.2 (A16)
S4: U2.30 (A17), U7.12 (Q4), U8.6 (A4), U9.30 (A17)
S5: U2.1 (A18), U7.15 (Q5), U8.7 (A5), U9.1 (A18)
S6: U3.5, U6.10, U7.16 (Q6), U8.8 (A6)
S7: U4.1 (A14), U7.19 (Q7), U8.9 (A7)
VCC: D1.2 (A), J2.2, J3.2
~CS1: U2.22 (CE#), U6.8
~CS2: U3.6, U9.22 (CE#)
~CS3: U3.3, U4.20 (~CS)
~IORQ: J1.31, U5.1 (G)
~MRQ: J1.27, U1.13
~P=R: U5.19 (P=R), U6.4, U6.13
~RD: J1.28, U2.24 (OE#), U4.22 (~OE), U6.12, U9.24 (OE#)
~REN: U1.5, U3.11, U6.2
~RES: J1.34, U7.1 (~Mr)
~WR: J1.30, U2.29 (WE#), U4.27 (~WE), U6.5, U9.29 (WE#)

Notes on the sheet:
512 kb static memory
VIN
EXPANSION BOARD CONNECTOR
0x94
VOUT
32 kb static memory
~{INT} ~{IORQ} ~{M1} ~{LOCK} ~{DEW/R2425} PHI2
Only active on ~{IORQ}
RAM Access Memory 2
Bank-switchable 32kb of memory 0xA000-0xDFFF
Because of timing contraints, ~{WR} needs to be combined with ~{P=R}
Bank-switchable 1Mb of memory 0xE000-0xFFFF
See also Field Support Manual: Diagram 3.8.1
Power lines
Chip select circuitry
BANK SWITCHING CONTROL LINES
ADDR >= 0xE000, then both A13 and A14 are high
~{WAIT} ~{RES} ~{RFSH} PHI T4M
Whether one of the two RAM chips should be set active
Port number 0x94 selects D-type flip-flop 0x94 = 1001 0100

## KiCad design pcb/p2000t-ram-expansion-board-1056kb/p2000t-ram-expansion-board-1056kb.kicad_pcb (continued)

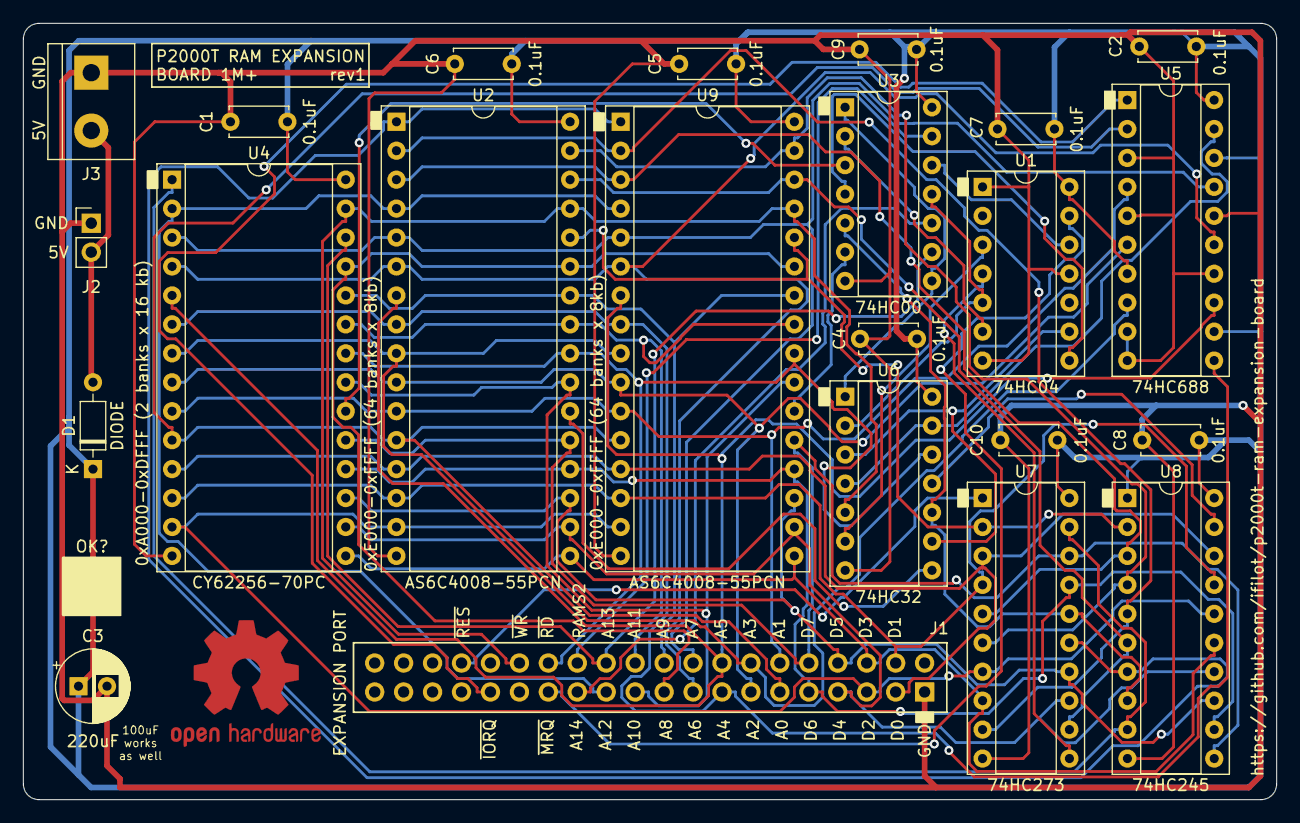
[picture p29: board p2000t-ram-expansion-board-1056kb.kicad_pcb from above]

Board: 2 copper layers, 110.0 x 68.1 mm, 24 parts (1 on the bottom side), 53 nets.

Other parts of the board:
LOGO1: OSHW-Logo2_14.6x12mm_Copper_AND_Mask

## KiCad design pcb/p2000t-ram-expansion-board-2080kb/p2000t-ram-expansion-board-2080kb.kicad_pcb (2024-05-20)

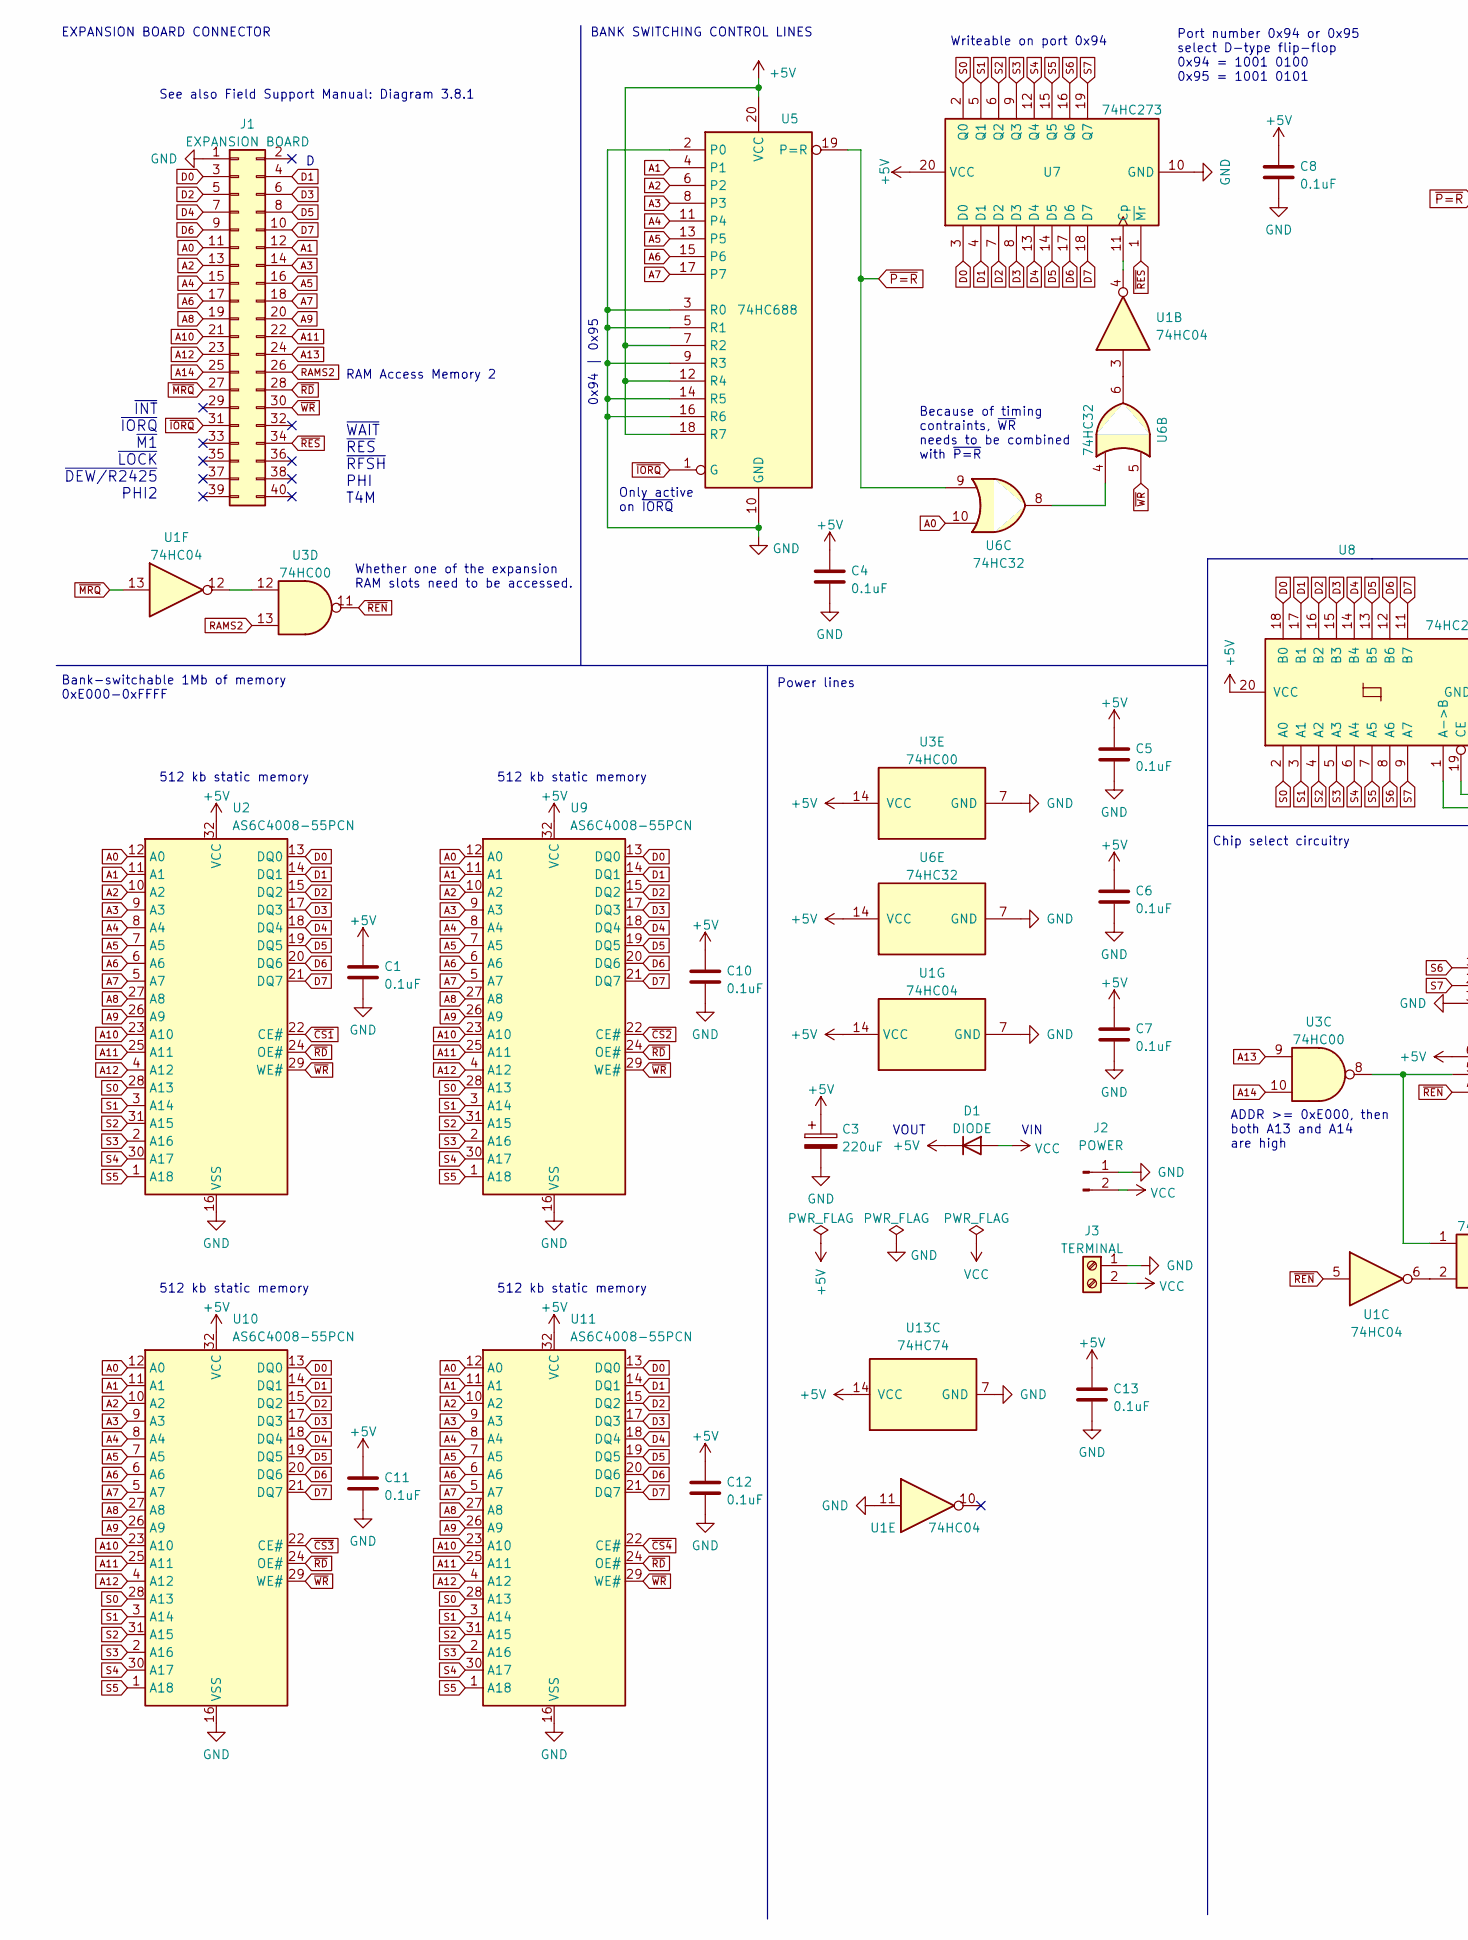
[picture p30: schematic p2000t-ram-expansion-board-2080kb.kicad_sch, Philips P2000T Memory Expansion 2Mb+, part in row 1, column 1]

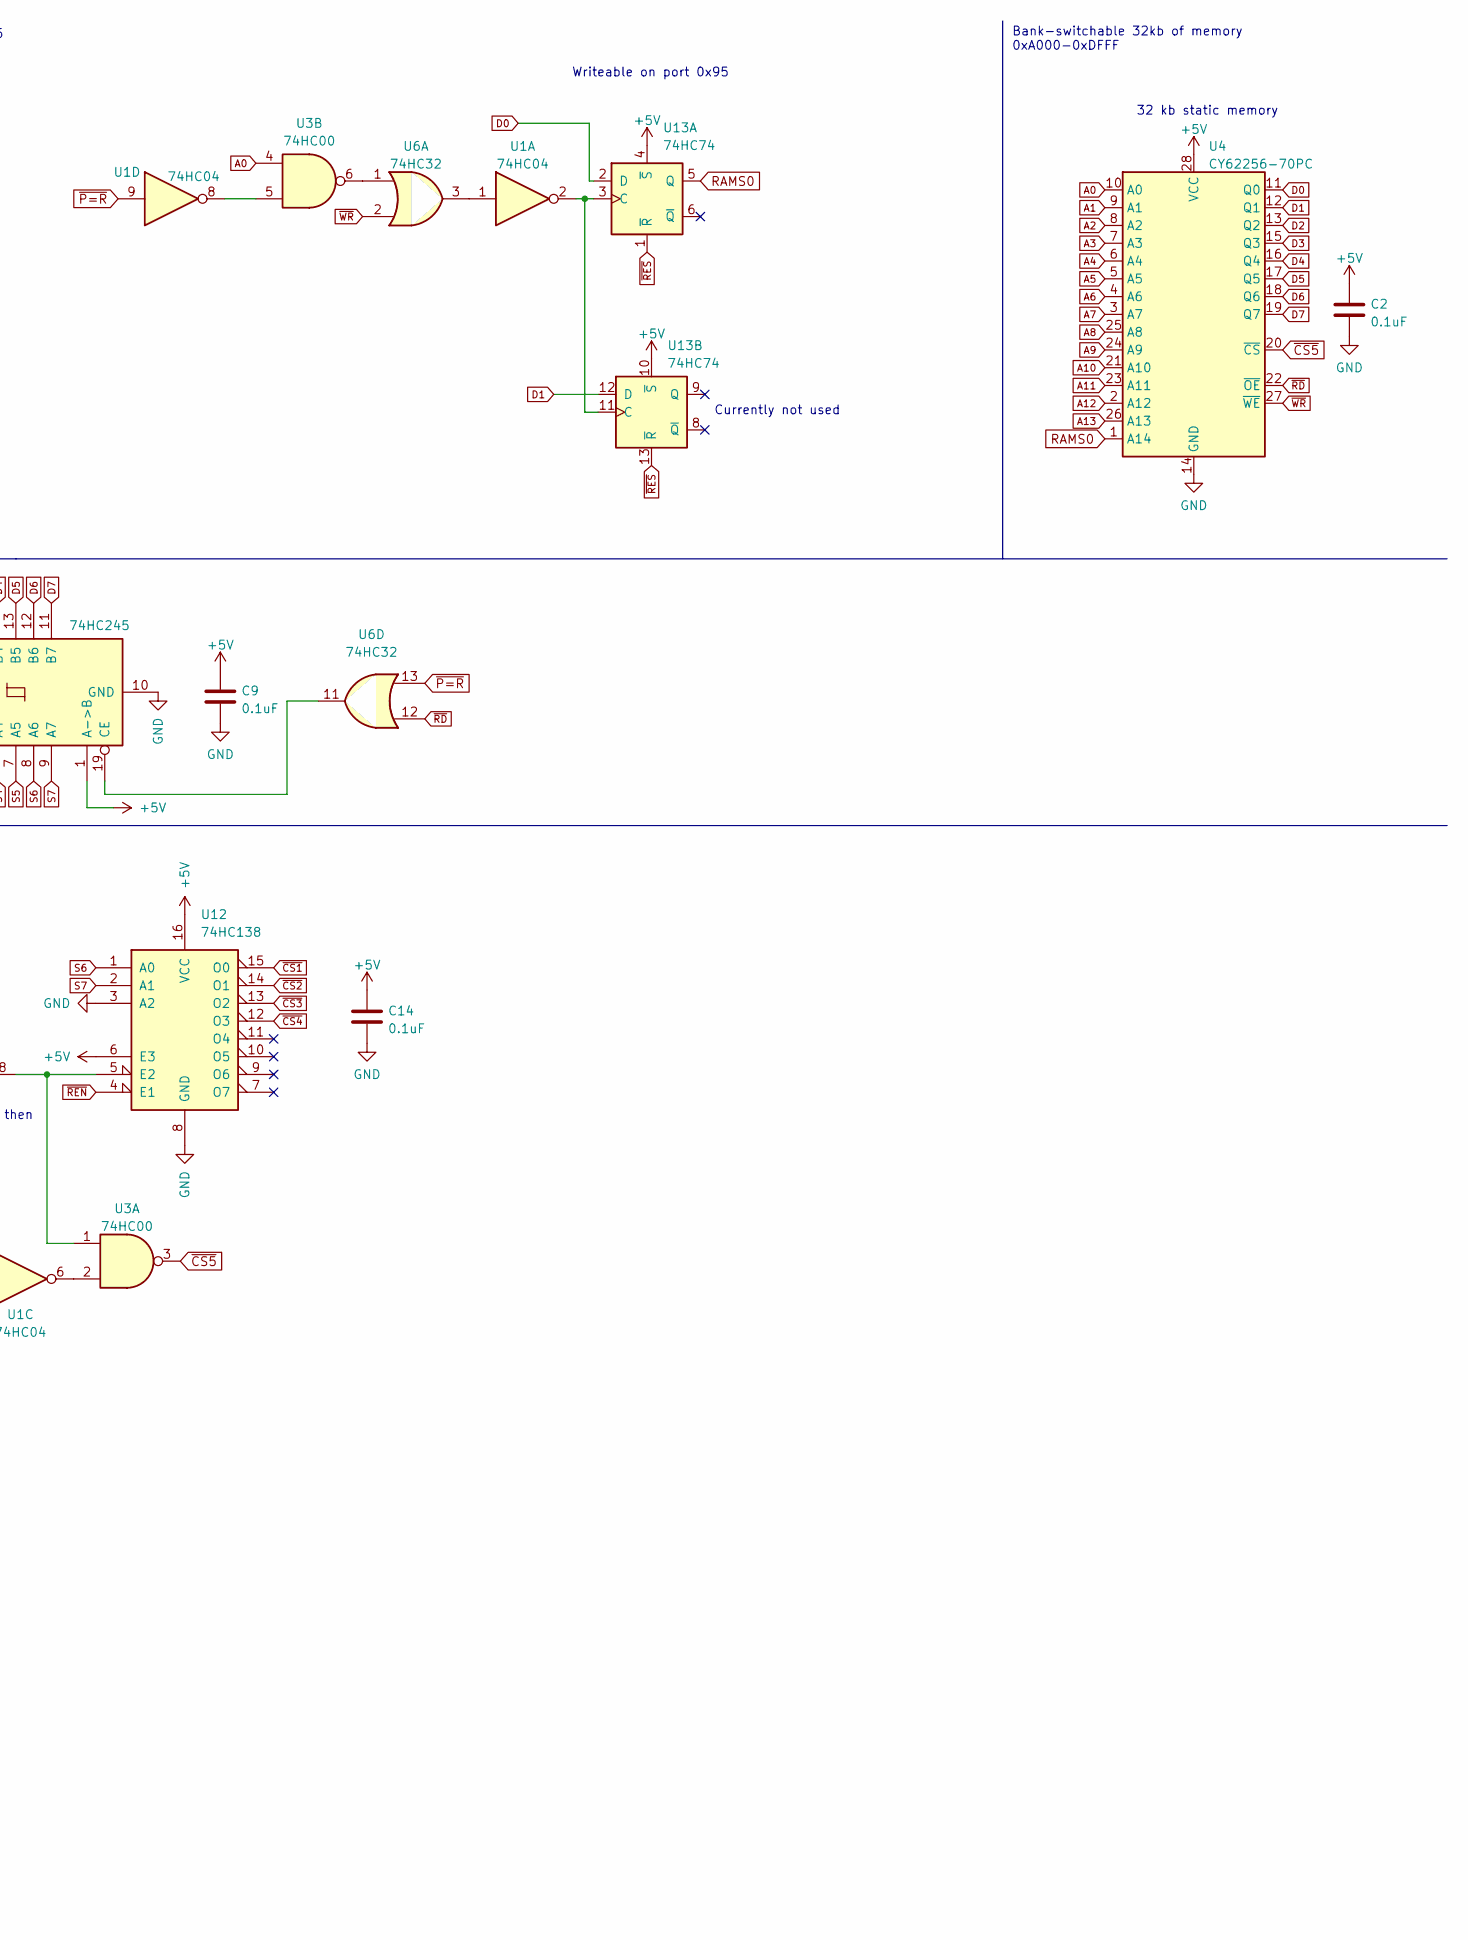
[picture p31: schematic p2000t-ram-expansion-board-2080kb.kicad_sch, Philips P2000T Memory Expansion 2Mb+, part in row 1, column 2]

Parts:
C1, C2, C4, C5, C6, C7, C8, C9, C10, C11, C12, C13, C14: 0.1uF; C_Disc_D5.0mm_W2.5mm_P5.00mm
C3: 220uF; CP_Radial_D6.3mm_P2.50mm
D1: DIODE; D_DO-35_SOD27_P7.62mm_Horizontal
J1: EXPANSION BOARD; PinHeader_2x20_P2.54mm_Vertical
J2: POWER; PinHeader_1x02_P2.54mm_Vertical
J3: TERMINAL; TerminalBlock_bornier-2_P5.08mm
U1: 74HC04; DIP-14_W7.62mm_Socket
U2, U9, U10, U11: AS6C4008-55PCN; DIP-32_W15.24mm_Socket
U3: 74HC00; DIP-14_W7.62mm_Socket
U4: CY62256-70PC; DIP-28_W15.24mm_Socket
U5: 74HC688; DIP-20_W7.62mm_Socket
U6: 74HC32; DIP-14_W7.62mm_Socket
U7: 74HC273; DIP-20_W7.62mm_Socket
U8: 74HC245; DIP-20_W7.62mm_Socket
U12: 74HC138; DIP-16_W7.62mm_Socket
U13: 74HC74; DIP-14_W7.62mm_Socket

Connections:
+5V: C1.1, C2.1, C3.1, C4.1, C5.1, C6.1, C7.1, C8.1, C9.1, C10.1, C11.1, C12.1, C13.1, C14.1, D1.1 (K), U1.14 (VCC), U2.32 (VCC), U3.14 (VCC), U4.28 (VCC), U5.7 (R2), U5.12 (R4), U5.18 (R7), U5.20 (VCC), U6.14 (VCC), U7.20 (VCC), U8.1 (A->B), U8.20 (VCC), U9.32 (VCC), U10.32 (VCC), U11.32 (VCC), U12.6 (E3), U12.16 (VCC), U13.4 (~S), U13.10 (~S), U13.14 (VCC)
A0: J1.11, U2.12 (A0), U3.4, U4.10 (A0), U6.10, U9.12 (A0), U10.12 (A0), U11.12 (A0)
A1: J1.12, U2.11 (A1), U4.9 (A1), U5.4 (P1), U9.11 (A1), U10.11 (A1), U11.11 (A1)
A2: J1.13, U2.10 (A2), U4.8 (A2), U5.6 (P2), U9.10 (A2), U10.10 (A2), U11.10 (A2)
A3: J1.14, U2.9 (A3), U4.7 (A3), U5.8 (P3), U9.9 (A3), U10.9 (A3), U11.9 (A3)
A4: J1.15, U2.8 (A4), U4.6 (A4), U5.11 (P4), U9.8 (A4), U10.8 (A4), U11.8 (A4)
A5: J1.16, U2.7 (A5), U4.5 (A5), U5.13 (P5), U9.7 (A5), U10.7 (A5), U11.7 (A5)
A6: J1.17, U2.6 (A6), U4.4 (A6), U5.15 (P6), U9.6 (A6), U10.6 (A6), U11.6 (A6)
A7: J1.18, U2.5 (A7), U4.3 (A7), U5.17 (P7), U9.5 (A7), U10.5 (A7), U11.5 (A7)
A8: J1.19, U2.27 (A8), U4.25 (A8), U9.27 (A8), U10.27 (A8), U11.27 (A8)
A9: J1.20, U2.26 (A9), U4.24 (A9), U9.26 (A9), U10.26 (A9), U11.26 (A9)
A10: J1.21, U2.23 (A10), U4.21 (A10), U9.23 (A10), U10.23 (A10), U11.23 (A10)
A11: J1.22, U2.25 (A11), U4.23 (A11), U9.25 (A11), U10.25 (A11), U11.25 (A11)
A12: J1.23, U2.4 (A12), U4.2 (A12), U9.4 (A12), U10.4 (A12), U11.4 (A12)
A13: J1.24, U3.9, U4.26 (A13)
A14: J1.25, U3.10
D0: J1.3, U2.13 (DQ0), U4.11 (Q0), U7.3 (D0), U8.18 (B0), U9.13 (DQ0), U10.13 (DQ0), U11.13 (DQ0), U13.2 (D)
D1: J1.4, U2.14 (DQ1), U4.12 (Q1), U7.4 (D1), U8.17 (B1), U9.14 (DQ1), U10.14 (DQ1), U11.14 (DQ1), U13.12 (D)
D2: J1.5, U2.15 (DQ2), U4.13 (Q2), U7.7 (D2), U8.16 (B2), U9.15 (DQ2), U10.15 (DQ2), U11.15 (DQ2)
D3: J1.6, U2.17 (DQ3), U4.15 (Q3), U7.8 (D3), U8.15 (B3), U9.17 (DQ3), U10.17 (DQ3), U11.17 (DQ3)
D4: J1.7, U2.18 (DQ4), U4.16 (Q4), U7.13 (D4), U8.14 (B4), U9.18 (DQ4), U10.18 (DQ4), U11.18 (DQ4)
D5: J1.8, U2.19 (DQ5), U4.17 (Q5), U7.14 (D5), U8.13 (B5), U9.19 (DQ5), U10.19 (DQ5), U11.19 (DQ5)
D6: J1.9, U2.20 (DQ6), U4.18 (Q6), U7.17 (D6), U8.12 (B6), U9.20 (DQ6), U10.20 (DQ6), U11.20 (DQ6)
D7: J1.10, U2.21 (DQ7), U4.19 (Q7), U7.18 (D7), U8.11 (B7), U9.21 (DQ7), U10.21 (DQ7), U11.21 (DQ7)
GND: C1.2, C2.2, C3.2, C4.2, C5.2, C6.2, C7.2, C8.2, C9.2, C10.2, C11.2, C12.2, C13.2, C14.2, J1.1, J2.1, J3.1, U1.7 (GND), U1.11, U2.16 (VSS), U3.7 (GND), U4.14 (GND), U5.2 (P0), U5.3 (R0), U5.5 (R1), U5.9 (R3), U5.10 (GND), U5.14 (R5), U5.16 (R6), U6.7 (GND), U7.10 (GND), U8.10 (GND), U9.16 (VSS), U10.16 (VSS), U11.16 (VSS), U12.3 (A2), U12.8 (GND), U13.7 (GND)
unnamed: U1.1, U6.3
unnamed: U1.3, U6.6
unnamed: U1.6, U3.2
unnamed: U1.8, U3.5
unnamed: U1.12, U3.12
unnamed: U3.6, U6.1
unnamed: U6.4, U6.8
unnamed: U1.4, U7.11 (Cp)
unnamed: U6.11, U8.19 (CE)
unnamed: U3.1, U3.8, U12.5 (E2)
unnamed: U1.2, U13.3 (C), U13.11 (C)
RAMS0: U4.1 (A14), U13.5 (Q)
RAMS2: J1.26, U3.13
S0: U2.28 (A13), U7.2 (Q0), U8.2 (A0), U9.28 (A13), U10.28 (A13), U11.28 (A13)
S1: U2.3 (A14), U7.5 (Q1), U8.3 (A1), U9.3 (A14), U10.3 (A14), U11.3 (A14)
S2: U2.31 (A15), U7.6 (Q2), U8.4 (A2), U9.31 (A15), U10.31 (A15), U11.31 (A15)
S3: U2.2 (A16), U7.9 (Q3), U8.5 (A3), U9.2 (A16), U10.2 (A16), U11.2 (A16)
S4: U2.30 (A17), U7.12 (Q4), U8.6 (A4), U9.30 (A17), U10.30 (A17), U11.30 (A17)
S5: U2.1 (A18), U7.15 (Q5), U8.7 (A5), U9.1 (A18), U10.1 (A18), U11.1 (A18)
S6: U7.16 (Q6), U8.8 (A6), U12.1 (A0)
S7: U7.19 (Q7), U8.9 (A7), U12.2 (A1)
VCC: D1.2 (A), J2.2, J3.2
~CS1: U2.22 (CE#), U12.15 (O0)
~CS2: U9.22 (CE#), U12.14 (O1)
~CS3: U10.22 (CE#), U12.13 (O2)
~CS4: U11.22 (CE#), U12.12 (O3)
~CS5: U3.3, U4.20 (~CS)
~IORQ: J1.31, U5.1 (G)
~MRQ: J1.27, U1.13
~P=R: U1.9, U5.19 (P=R), U6.9, U6.13
~RD: J1.28, U2.24 (OE#), U4.22 (~OE), U6.12, U9.24 (OE#), U10.24 (OE#), U11.24 (OE#)
~REN: U1.5, U3.11, U12.4 (E1)
~RES: J1.34, U7.1 (~Mr), U13.1 (~R), U13.13 (~R)
~WR: J1.30, U2.29 (WE#), U4.27 (~WE), U6.2, U6.5, U9.29 (WE#), U10.29 (WE#), U11.29 (WE#)

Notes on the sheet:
512 kb static memory
VIN
EXPANSION BOARD CONNECTOR
0x94 | 0x95
VOUT
32 kb static memory
~{INT} ~{IORQ} ~{M1} ~{LOCK} ~{DEW/R2425} PHI2
Only active on ~{IORQ}
Writeable on port 0x95
RAM Access Memory 2
Currently not used
Bank-switchable 32kb of memory 0xA000-0xDFFF
Because of timing contraints, ~{WR} needs to be combined with ~{P=R}
Bank-switchable 1Mb of memory 0xE000-0xFFFF
See also Field Support Manual: Diagram 3.8.1
Power lines
Chip select circuitry
BANK SWITCHING CONTROL LINES
ADDR >= 0xE000, then both A13 and A14 are high
Writeable on port 0x94
~{WAIT} ~{RES} ~{RFSH} PHI T4M
Whether one of the expansion RAM slots need to be accessed.
Port number 0x94 or 0x95 select D-type flip-flop 0x94 = 1001 0100 0x95 = 1001 0101

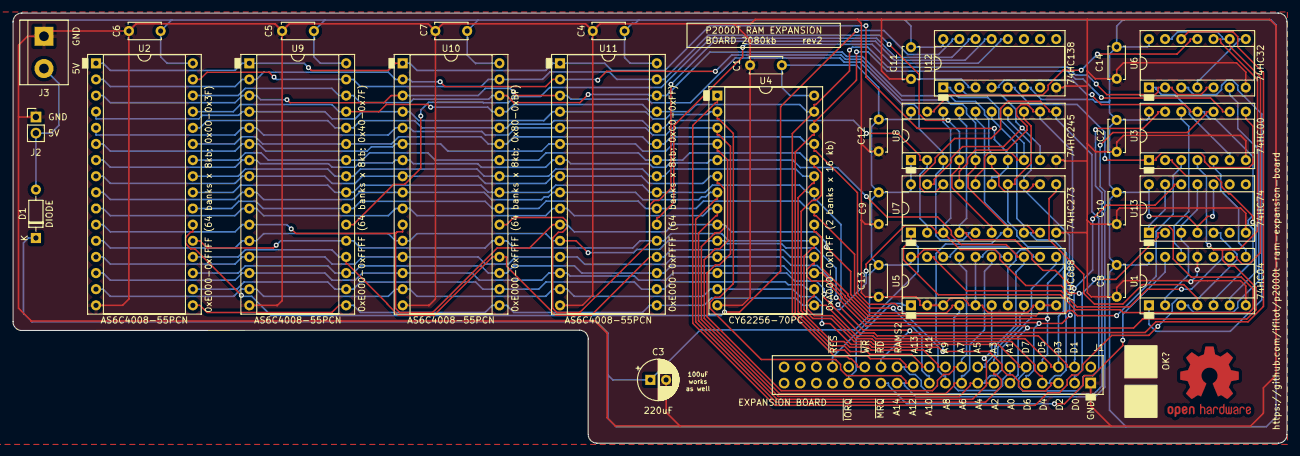
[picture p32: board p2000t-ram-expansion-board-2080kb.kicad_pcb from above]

Board: 2 copper layers, 200.5 x 67.7 mm, 32 parts (1 on the bottom side), 59 nets.

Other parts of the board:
LOGO1: OSHW-Logo2_14.6x12mm_Copper

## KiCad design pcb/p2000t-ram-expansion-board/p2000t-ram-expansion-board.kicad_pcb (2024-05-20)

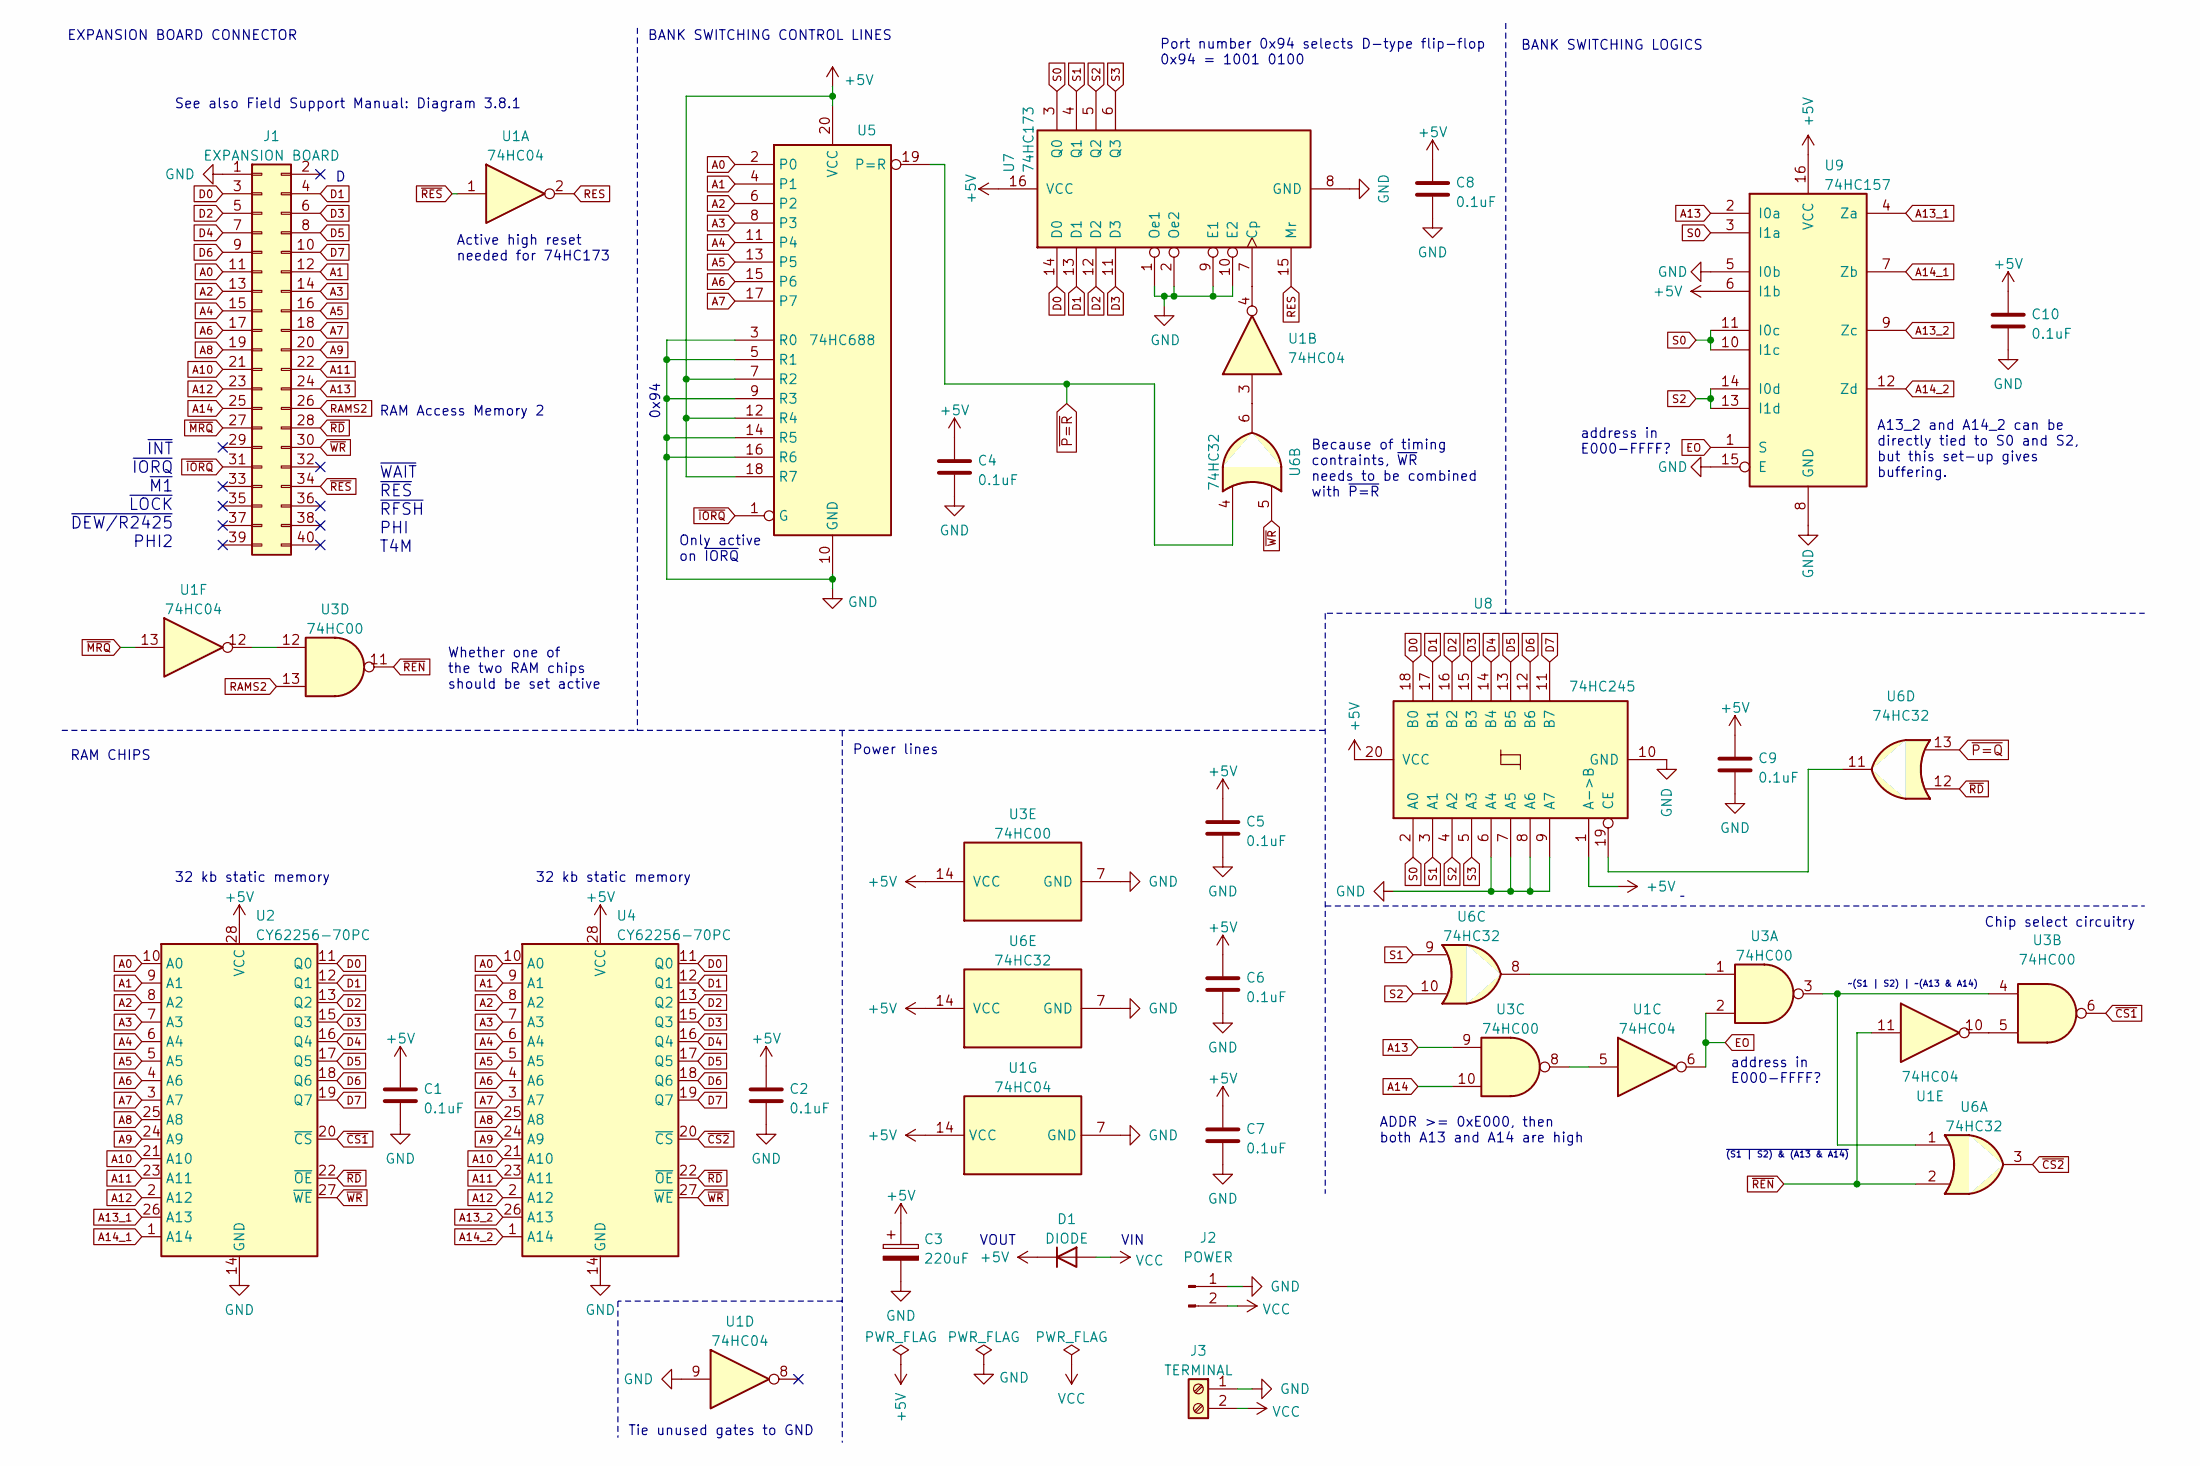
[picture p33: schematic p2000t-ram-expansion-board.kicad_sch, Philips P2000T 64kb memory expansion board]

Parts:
C1, C2, C4, C5, C6, C7, C8, C9, C10: 0.1uF; C_Disc_D5.0mm_W2.5mm_P5.00mm
C3: 220uF; CP_Radial_D6.3mm_P2.50mm
D1: DIODE; D_DO-35_SOD27_P7.62mm_Horizontal
J1: EXPANSION BOARD; PinHeader_2x20_P2.54mm_Vertical
J2: POWER; PinHeader_1x02_P2.54mm_Vertical
J3: TERMINAL; TerminalBlock_bornier-2_P5.08mm
U1: 74HC04; DIP-14_W7.62mm_Socket
U2, U4: CY62256-70PC; DIP-28_W15.24mm_Socket
U3: 74HC00; DIP-14_W7.62mm_Socket
U5: 74HC688; DIP-20_W7.62mm_Socket
U6: 74HC32; DIP-14_W7.62mm_Socket
U7: 74HC173; DIP-16_W7.62mm_Socket
U8: 74HC245; DIP-20_W7.62mm_Socket
U9: 74HC157; DIP-16_W7.62mm_Socket

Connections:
+5V: C1.1, C2.1, C3.1, C4.1, C5.1, C6.1, C7.1, C8.1, C9.1, C10.1, D1.1 (K), U1.14 (VCC), U2.28 (VCC), U3.14 (VCC), U4.28 (VCC), U5.7 (R2), U5.12 (R4), U5.18 (R7), U5.20 (VCC), U6.14 (VCC), U7.16 (VCC), U8.1 (A->B), U8.20 (VCC), U9.6 (I1b), U9.16 (VCC)
A0: J1.11, U2.10 (A0), U4.10 (A0), U5.2 (P0)
A1: J1.12, U2.9 (A1), U4.9 (A1), U5.4 (P1)
A2: J1.13, U2.8 (A2), U4.8 (A2), U5.6 (P2)
A3: J1.14, U2.7 (A3), U4.7 (A3), U5.8 (P3)
A4: J1.15, U2.6 (A4), U4.6 (A4), U5.11 (P4)
A5: J1.16, U2.5 (A5), U4.5 (A5), U5.13 (P5)
A6: J1.17, U2.4 (A6), U4.4 (A6), U5.15 (P6)
A7: J1.18, U2.3 (A7), U4.3 (A7), U5.17 (P7)
A8: J1.19, U2.25 (A8), U4.25 (A8)
A9: J1.20, U2.24 (A9), U4.24 (A9)
A10: J1.21, U2.21 (A10), U4.21 (A10)
A11: J1.22, U2.23 (A11), U4.23 (A11)
A12: J1.23, U2.2 (A12), U4.2 (A12)
A13: J1.24, U3.9, U9.2 (I0a)
A13_1: U2.26 (A13), U9.4 (Za)
A13_2: U4.26 (A13), U9.9 (Zc)
A14: J1.25, U3.10
A14_1: U2.1 (A14), U9.7 (Zb)
A14_2: U4.1 (A14), U9.12 (Zd)
D0: J1.3, U2.11 (Q0), U4.11 (Q0), U7.14 (D0), U8.18 (B0)
D1: J1.4, U2.12 (Q1), U4.12 (Q1), U7.13 (D1), U8.17 (B1)
D2: J1.5, U2.13 (Q2), U4.13 (Q2), U7.12 (D2), U8.16 (B2)
D3: J1.6, U2.15 (Q3), U4.15 (Q3), U7.11 (D3), U8.15 (B3)
D4: J1.7, U2.16 (Q4), U4.16 (Q4), U8.14 (B4)
D5: J1.8, U2.17 (Q5), U4.17 (Q5), U8.13 (B5)
D6: J1.9, U2.18 (Q6), U4.18 (Q6), U8.12 (B6)
D7: J1.10, U2.19 (Q7), U4.19 (Q7), U8.11 (B7)
EO: U1.6, U3.2, U9.1 (S)
GND: C1.2, C2.2, C3.2, C4.2, C5.2, C6.2, C7.2, C8.2, C9.2, C10.2, J1.1, J2.1, J3.1, U1.7 (GND), U1.9, U2.14 (GND), U3.7 (GND), U4.14 (GND), U5.3 (R0), U5.5 (R1), U5.9 (R3), U5.10 (GND), U5.14 (R5), U5.16 (R6), U6.7 (GND), U7.1 (Oe1), U7.2 (Oe2), U7.8 (GND), U7.9 (E1), U7.10 (E2), U8.6 (A4), U8.7 (A5), U8.8 (A6), U8.9 (A7), U8.10 (GND), U9.5 (I0b), U9.8 (GND), U9.15 (E)
unnamed: U1.3, U6.6
unnamed: U1.4, U7.7 (Cp)
unnamed: U1.5, U3.8
unnamed: U1.10, U3.5
unnamed: U1.12, U3.12
unnamed: U3.1, U6.8
unnamed: U3.3, U3.4, U6.1
unnamed: U6.11, U8.19 (CE)
RAMS2: J1.26, U3.13
RES: U1.2, U7.15 (Mr)
S0: U7.3 (Q0), U8.2 (A0), U9.3 (I1a), U9.10 (I1c), U9.11 (I0c)
S1: U6.9, U7.4 (Q1), U8.3 (A1)
S2: U6.10, U7.5 (Q2), U8.4 (A2), U9.13 (I1d), U9.14 (I0d)
S3: U7.6 (Q3), U8.5 (A3)
VCC: D1.2 (A), J2.2, J3.2
~CS1: U2.20 (~CS), U3.6
~CS2: U4.20 (~CS), U6.3
~IORQ: J1.31, U5.1 (G)
~MRQ: J1.27, U1.13
~RD: J1.28, U2.22 (~OE), U4.22 (~OE), U6.12
~REN: U1.11, U3.11, U6.2
~RES: J1.34, U1.1
~WR: J1.30, U2.27 (~WE), U4.27 (~WE), U6.5

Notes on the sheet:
VIN
EXPANSION BOARD CONNECTOR
0x94
VOUT
32 kb static memory
~{INT} ~{IORQ} ~{M1} ~{LOCK} ~{DEW/R2425} PHI2
Only active on ~{IORQ}
RAM Access Memory 2
address in E000-FFFF?
Because of timing contraints, ~{WR} needs to be combined with ~{P=R}
BANK SWITCHING LOGICS
RAM CHIPS
See also Field Support Manual: Diagram 3.8.1
~{(S1 | S2) & (A13 & A14)}
Power lines
Chip select circuitry
BANK SWITCHING CONTROL LINES
Tie unused gates to GND
A13_2 and A14_2 can be directly tied to S0 and S2, but this set-up gives buffering.
ADDR >= 0xE000, then both A13 and A14 are high
~{WAIT} ~{RES} ~{RFSH} PHI T4M
Active high reset needed for 74HC173
Whether one of the two RAM chips should be set active
Port number 0x94 selects D-type flip-flop 0x94 = 1001 0100
~(S1 | S2) | ~(A13 & A14)

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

Board: 2 copper layers, 110.0 x 68.1 mm, 24 parts (1 on the bottom side), 54 nets.

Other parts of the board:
LOGO1: OSHW-Logo2_14.6x12mm_Copper_AND_Mask

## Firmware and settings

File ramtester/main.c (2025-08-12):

/**************************************************************************
 *                                                                        *
 *   Author: Ivo Filot <ivo@ivofilot.nl>                                  *
 *                                                                        *
 *   P2000T-RAMTESTER is free software:                                   *
 *   you can redistribute it and/or modify it under the terms of the      *
 *   GNU General Public License as published by the Free Software         *
 *   Foundation, either version 3 of the License, or (at your option)     *
 *   any later version.                                                   *
 *                                                                        *
 *   P2000T-RAMTESTER software is distributed in the hope that it will    *
 *   be useful, but WITHOUT ANY WARRANTY; without even the implied        *
 *   warranty of MERCHANTABILITY or FITNESS FOR A PARTICULAR PURPOSE.     *
 *   See the GNU General Public License for more details.                 *
 *                                                                        *
 *   You should have received a copy of the GNU General Public License    *
 *   along with this program.  If not, see http://www.gnu.org/licenses/.  *
 *                                                                        *
 **************************************************************************/

/*
 * This short application will perform a set of tests on the RAM expansion
 * board of a P2000T. Note that this application assumes that the stack starts
 * at location 0x9FFF and grows downwards (i.e. with decreasing memory address).
 *
 * This program works for both the 64KiB expansion board as well as the
 * 1056KiB expansion board.
 */

#include <string.h>
#include <stdint.h>
#include <stdio.h>
#include <stdlib.h>
#include <math.h>

#include "config.h"
#include "constants.h"
#include "memory.h"
#include "util.h"
#include "stack.h"
#include "z80.h"
#include "ramtest.h"
#include "terminal.h"
#include "bankcounting.h"

#define MEMEXPNONE  0       // no expansion
#define MEMEXP16    1       // A000-DFFF, no banking
#define MEMEXP24    2       // A000-FFFF, no banking
#define MEMEXP64    3       // A000-FFFF, 6 banks
#define MEMEXP128   4       // A000-FFFF, 14 banks
#define MEMEXP256   5       // A000-FFFF, 30 banks
#define MEMEXP384   6       // A000-FFFF, 46 banks
#define MEMEXP512   7       // A000-FFFF, 62 banks
#define MEMEXP1056  8
#define MEMEXP2080  9

uint8_t test_passed[5];

// forward declarations
void init(void);

void set_bank_highmem(uint8_t bank);

uint8_t read_bank(void);

void ram_test_01(void);
void ram_test_02(void);
void ram_test_03(void);
void ram_test_04(void);
void ram_test_05(void);
void ram_test_06(void);
void ram_test_07(void);

uint8_t test_bank_helper(uint8_t startbank, uint8_t stopbank, uint8_t *uppermembanks,
                         uint8_t *expansion_type, uint8_t banktypefail, uint16_t szdetect);
void test_fixed_pattern(uint8_t pattern, uint8_t check_id);
void write_termbuffer_value(uint8_t i, uint8_t color);
static uint8_t fingerprint(uint8_t i) { return (uint8_t)(0xA5u ^ i); }

// global variables
uint8_t expansion_type = 0;
uint8_t highmemsectors = 0;       // number of high memory sectors
uint8_t highmembanks = 0;         // number of high memory banks
uint16_t uppermembanks = 0;       // number of upper memory banks

int main(void) {
    init();

    // reset passed tests array
    memset(test_passed, 0x00, 5);

    // perform test on high memory
    ram_test_01();

    // if there are no high memory banks, stop here
    if(highmemsectors != 0) {
        ram_test_02();        
        ram_test_03();
        ram_test_04();
        ram_test_05();
        ram_test_06();
        ram_test_07();
    }

    print_info("",0);   // print empty line
    print_inline_color("-= ALL DONE PERFORMING RAM TESTS =-", COL_CYAN);

    // show summary
    print_info("",0);   // print empty line
    print_inline_color("-= SUMMARY =-", COL_CYAN);
    char buf[50];
    for(uint8_t i=0; i<5; i++) {
        if(test_passed[i] == 0) {
            sprintf(buf, "  * TEST %u: %cPASSED%c", i+1, COL_GREEN, COL_WHITE);
            print_info(buf, 0);
        } else {
            sprintf(buf, "  * TEST %u: %cFAILED%c; %u ERROR(S) ENCOUNTERED", i+1, COL_RED, COL_WHITE, test_passed[i]);
            print_info(buf, 0);
        }
        
    }
    write_stack_pointer();

    // put in infinite loop
    for(;;){}
}

/*
 * Test 1: Test high memory
 * ========================
 *
 * Perform a quick test where 0x55 is written to 0xA000, 0xB000, 0xC000,
 * and 0xD000 and where it is checked that this byte can be read back.
 */
void ram_test_01(void) {
    print_info("Test 1: High memory", 0);
    for(uint8_t i=0xA; i<=0xD; i++) {

        memory[i * 0x1000] = 0x55;

        for(uint8_t j=0xA; j<=0xD; j++) {
            if(i == j) {
                continue;
            }
            memory[j * 0x1000] = 0x00;
        }

        if(memory[i * 0x1000] == 0x55) {
            sprintf(&termbuffer[(i - 0xA)*6], "%c%04X%c", COL_GREEN, i * 0x1000, COL_WHITE);
            highmemsectors++;
        } else {
            sprintf(&termbuffer[(i - 0xA)*6], "%c%04X%c", COL_RED, i * 0x1000, COL_WHITE);
        }
    }
    terminal_printtermbuffer();

    if(highmemsectors == 0) {
        expansion_type = 0;
        print_info("No memory expansion card present.", 0);
    }
}

/*
 * Test 2: Bank switching
 * ======================
 *
 * Perform another quick test where a byte is written to 0xE000 and 0xF000
 * where the value written depends on the currently active bank switch. Next,
 * each bank is tested for being able to read this value back.
 * 
 * This test is also used to determine which type of expansion board the user has.
 */
void ram_test_02(void) {
    print_info("Test 2: Determine number of RAM banks", 0);
    uppermembanks = count_banks();
    sprintf(termbuffer, "%c%u%c RAM banks found", COL_CYAN, uppermembanks, COL_WHITE);
    terminal_printtermbuffer();

    switch(uppermembanks) {
        case 0:
            print_inline_color("16 KiB memory expansion detected", COL_CYAN);
        break;
        case 1:
            print_inline_color("32 KiB memory expansion detected", COL_CYAN);
        break;
        case 6:
            print_inline_color("64 KiB memory expansion detected", COL_CYAN);
        break;
        case 14:
            print_inline_color("128 KiB memory expansion detected", COL_CYAN);
        break;
        case 30:
            print_inline_color("256 KiB memory expansion detected", COL_CYAN);
        break;
        case 46:
            print_inline_color("384 KiB memory expansion detected", COL_CYAN);
        break;
        case 62:
            print_inline_color("512 KiB memory expansion detected", COL_CYAN);
        break;
        case 128:
            print_inline_color("1056 KiB memory expansion detected", COL_CYAN);
        break;
        case 256:
            print_inline_color("2080 KiB memory expansion detected", COL_CYAN);
        break;
        default:
            print_inline_color("Unknown memory expansion, please inform developer", COL_RED);
        break;
    }
}

/*
* Test 3: Reading bank register
* =============================
*
* Final quick test where a value is written to the bank register to swap
* the bank and check whether that value can be read back.
*/
void ram_test_03(void) {
    print_info("Test 3: Reading bank register", 0);
    uint16_t bankschecked = 0;
    for(uint16_t i=0; i<uppermembanks; i++) {
        set_bank(i);
        
        if(read_bank() == i) {
            bankschecked++;
        }
    }
    if(bankschecked == uppermembanks) {
        sprintf(termbuffer, "  %cOK%c Reading bank register", COL_GREEN, COL_WHITE);
    } else {
        sprintf(termbuffer, "  %cFAIL%c Reading bank register", COL_RED, COL_WHITE);
    }
    terminal_printtermbuffer();
}

/*
* Test 4: Test lower and higher memory
* ====================================
*
* Check that values can be written to and read back from lower and upper
* memory
*/
void ram_test_04(void) {
    set_bank(0);
    print_info("Test 4: Lower and higher memory", 0);
    memset(&memory[LOWMEM], 0x55, STACK - LOWMEM);
    uint16_t lowmem_count = count_ram_bytes(&memory[LOWMEM], 0x55, STACK - LOWMEM);
    memset(&memory[LOWMEM], 0xAA, STACK - LOWMEM);
    lowmem_count += count_ram_bytes(&memory[LOWMEM], 0xAA, STACK - LOWMEM);
    memset(&memory[LOWMEM], 0x00, STACK - LOWMEM);
    lowmem_count += count_ram_bytes(&memory[LOWMEM], 0x00, STACK - LOWMEM);
    memset(&memory[LOWMEM], 0xFF, STACK - LOWMEM);
    lowmem_count += count_ram_bytes(&memory[LOWMEM], 0xFF, STACK - LOWMEM);

    if(lowmem_count == 0) {
        sprintf(termbuffer, "  0x%04X - 0x%04X: %cOK", LOWMEM, STACK-1, COL_GREEN);
    } else {
        sprintf(termbuffer, "  0x%04X - 0x%04X: %c%u miscounts", LOWMEM, STACK-1, COL_RED, lowmem_count);
    }
    terminal_printtermbuffer();

    memset(&memory[HIGHMEM_START], 0x55, HIGHMEM_STOP - HIGHMEM_START - 1);
    uint16_t uppermem_count = count_ram_bytes(&memory[HIGHMEM_START], 0x55, HIGHMEM_STOP - HIGHMEM_START);
    memset(&memory[HIGHMEM_START], 0xAA, HIGHMEM_STOP - HIGHMEM_START - 1);
    uppermem_count += count_ram_bytes(&memory[HIGHMEM_START], 0xAA, HIGHMEM_STOP - HIGHMEM_START);
    memset(&memory[HIGHMEM_START], 0x00, HIGHMEM_STOP - HIGHMEM_START - 1);
    uppermem_count += count_ram_bytes(&memory[HIGHMEM_START], 0x00, HIGHMEM_STOP - HIGHMEM_START);
    memset(&memory[HIGHMEM_START], 0xFF, HIGHMEM_STOP - HIGHMEM_START - 1);
    uppermem_count += count_ram_bytes(&memory[HIGHMEM_START], 0xFF, HIGHMEM_STOP - HIGHMEM_START);

    if(uppermem_count == 0) {
        sprintf(termbuffer, "  0x%04X - 0x%04X: %cOK", HIGHMEM_START, HIGHMEM_STOP, COL_GREEN);
    } else {
        sprintf(termbuffer, "  0x%04X - 0x%04X: %c%u miscounts", HIGHMEM_START, HIGHMEM_STOP, COL_RED, uppermem_count);
    }
    terminal_printtermbuffer();
}

/*
 * Test 5: Bank switchable memory
 * ===================================
 *
 * Check that memory is conserved upon bank switching
 */
void ram_test_05(void) {   
    print_info("Test 5: Bank switching memory", 0);
    print_info("  Writing data to banks", 0);

    for(uint16_t i=0; i<uppermembanks; i++) {
        set_bank(i);
        uint8_t t = tag_byte(0x00, (uint8_t)i);
        memset(&memory[BANKMEM_START], t, BANKMEM_STOP - BANKMEM_START + 1);
        write_termbuffer_value((uint8_t)i, COL_CYAN);

        if((i+1) % 8 == 0) {
            terminal_printtermbuffer();
        }
    }

    // also print result when total is not divisible by 8
    if(uppermembanks % 8 != 0) {
        terminal_printtermbuffer();
    }

    print_info("  Testing data on banks", 0);

    for(uint16_t i=0; i<uppermembanks; i++) {
        set_bank(i);
        uint8_t t = tag_byte(0x00, (uint8_t)i);
        uint16_t miscounts = count_ram_bytes(&memory[BANKMEM_START], t, BANKMEM_STOP - BANKMEM_START + 1);
        if(miscounts == 0) {
            write_termbuffer_value(i, COL_GREEN);
        } else {
            write_termbuffer_value((uint8_t)i, COL_RED);
            test_passed[0]++;
        }

        if((i+1) % 8 == 0) {
            terminal_printtermbuffer();
        }
    }

    // also print result when total is not divisible by 8
    if(uppermembanks % 8 != 0) {
        terminal_printtermbuffer();
    }
}

/*
 * Test 6: Checkerboard test
 * ===================================
 *
 * Check that memory is conserved upon bank switching
 */
void ram_test_06(void) {   
    print_info("Test 6: Checkerboard test", 0);
    test_fixed_pattern(0x55, 1);
    test_fixed_pattern(0xAA, 2);
}

/*
 * Test 7: Stuck-at-transition
 * ===================================
 *
 * Check that memory is conserved upon bank switching
 */
void ram_test_07(void) {   
    print_info("Test 7: Stuck at transition", 0);
    test_fixed_pattern(0x00, 3);
    test_fixed_pattern(0xFF, 4);
}

void set_bank_highmem(uint8_t bank) {
    z80_outp(0x95, bank);
}

/**
 * @brief Read the current bank from the bank register
 * 
 * @return uint8_t bank id
 */
uint8_t read_bank(void) {
    return z80_inp(0x94);
}

/**
 * Perform a series of simple read/write tests on banks to determine the total
 * number of banks.
 */
uint8_t test_bank_helper(uint8_t startbank, uint8_t stopbank, uint8_t *uppermembanks,
                        uint8_t *expansion_type, uint8_t banktypefail, uint16_t szdetect) {
    
    char buf[50];

    // write test bit to new banks to be probed
    for(uint8_t i=startbank; i<stopbank; i++) {
        set_bank(i);
        memory[0xE000] = i;
        memory[0xF000] = i | 0x80;
    }

    // read back and test
    for(uint8_t i=startbank; i<stopbank; i++) {
        set_bank(i);
        if(memory[0xE000] == i && 
           memory[0xF000] == (i | 0x80)) {
            (*uppermembanks)++;
        } else { // early exit when not possible to avoid generating false positives
            break;
        }
    }

    // analyse results
    if((*uppermembanks) != stopbank) {
        (*expansion_type) = banktypefail;
        sprintf(buf, "%u KiB expansion card detected", szdetect);
        print_inline_color(buf, COL_GREEN);
        return 1;
    } else {
        sprintf(termbuffer, "  Banks %u - %u probed", startbank, stopbank-1);
        terminal_printtermbuffer();
        return 0;
    }
}

/**
 * Apply a fixed byte pattern to a set of RAM banks and verify whether these can be
 * read back.
 */
void test_fixed_pattern(uint8_t pattern, uint8_t check_id) {
    sprintf(termbuffer, "  Writing 0x%02X to banks", pattern);
    terminal_printtermbuffer();
    uint8_t miscounts = 0;

    for(uint16_t i=0; i<uppermembanks; i++) {
        set_bank(i);
        memset(&memory[BANKMEM_START], pattern, BANKMEM_STOP - BANKMEM_START + 1);
        write_termbuffer_value((uint8_t)i, COL_CYAN);

        if((i+1) % 8 == 0) {
            terminal_printtermbuffer();
        }
    }

    // also print result when total is not divisible by 8
    if(uppermembanks % 8 != 0) {
        terminal_printtermbuffer();
    }

    sprintf(termbuffer, "  Testing 0x%02X on banks", pattern);
    terminal_printtermbuffer();

    for(uint16_t i=0; i<uppermembanks; i++) {
        set_bank(i);
        uint16_t miscounts_bank = count_ram_bytes(&memory[BANKMEM_START], pattern, BANKMEM_STOP - BANKMEM_START + 1);
        if(miscounts_bank == 0) {
            write_termbuffer_value((uint8_t)i, COL_GREEN);
        } else {
            write_termbuffer_value((uint8_t)i, COL_RED);
            test_passed[check_id]++;
        }

        if((i+1) % 8 == 0) {
            terminal_printtermbuffer();
        }
    }

    // also print result when total is not divisible by 8
    if(uppermembanks % 8 != 0) {
        terminal_printtermbuffer();
    }
}

static inline char hex1(uint8_t v) {
    static const char hexd[] = "0123456789ABCDEF";  // size = 17 (includes '\0')
    return hexd[v & 0xF];
}

/**
 * Helper function to write 4-byte colored hex value to string buffer;
 * used to indicate RAM banks.
 */
void write_termbuffer_value(uint8_t i, uint8_t color) {
    // 4 visible chars + NUL; we intentionally copy 5 bytes into a 4-byte slot
    // so the NUL becomes the first byte of the next cell.
    char tmp[5];
    tmp[0] = (char)color;
    tmp[1] = hex1((uint8_t)(i >> 4));
    tmp[2] = hex1((uint8_t)i);
    tmp[3] = (char)COL_WHITE;
    tmp[4] = '\0';
    memcpy(&termbuffer[(i % 8) * 4], tmp, 5);
}

/**
 * @brief Initialize the environment
 */
void init(void) {
    clear_screen();
    terminal_init(3, 20);
    vidmem[0x50] = TEXT_DOUBLE;
    vidmem[0x50+1] = COL_CYAN;
    sprintf(&vidmem[0x50+2], "RAM TESTER");

    // insert cursor
    sprintf(termbuffer, "%c>%c", COL_CYAN, COL_WHITE);
    terminal_redoline();
    
    set_bank(0);    // always set bank 0 upon initializati`on
    sprintf(&vidmem[0x50*22], "Version: %s", __VERSION__);
    sprintf(&vidmem[0x50*23], "Compiled at: %s / %s", __DATE__, __TIME__);
}

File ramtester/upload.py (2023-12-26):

#
# Quick upload method to development cartridge
#
# Requirements: pyserial and tqdm modules
#

import numpy as np
import serial
import serial.tools.list_ports
from tqdm import tqdm

def main():
    ser = connect()
    upload_rom(ser, 'main.rom', 3)
    ser.close()

def connect():
    # autofind any available boards
    ports = serial.tools.list_ports.comports()
    portfound = None
    for port in ports:
        if port.pid == 54 and port.vid == 0x2341:
            portfound = port.device
            break

    # specify the COM port below
    if portfound:
        ser = serial.Serial(portfound, 
                            19200, 
                            bytesize=serial.EIGHTBITS,
                            parity=serial.PARITY_NONE,
                            stopbits=serial.STOPBITS_ONE,
                            timeout=None)  # open serial port
                   
        if not ser.isOpen():
            ser.open()
    
    return ser

def test_board_id(ser):
    """
    Check that a connection to the board can be established
    """
    ser.write(b'READINFO')
    res = ser.read(8)
    print(res)
    res = ser.read(16)
    print(res)
    
    if res == b'Ph2k-32u4-v1.0.3':
        print('Connection established. All ok!')
    else:
        raise Exception('Cannot connect. Invalid response.')

def upload_rom(ser, filename, bank=0):
    """
    Upload the ROM file
    """
    # check that a connection to the board can be established
    ser.write(b'DEVIDSST')
    rsp = ser.read(8)
    rsp = ser.read(2)
    if rsp != bytearray([0xBF,0xB7]):
        raise Exception("Incorrect chip id.")
        
    f = open(filename, 'rb')
    data = bytearray(f.read())
    f.close()
    
    # wipe second bank
    print('Wiping bank %i' % bank)
    for i in tqdm(range(0,4)):
        ser.write(b'ESST00%02X' % ((i+bank*4) * 0x10))
        res = ser.read(8)
        res = ser.read(2)

    # expand data to first 256 byte increment
    sz = len(data)
    exp = (sz // 256 + 1) * 256
    data.extend(np.zeros(exp - sz))
    
    offset = bank * 16 * 1024 // 256

    print('Writing data to bank %i' % bank)
    for i in tqdm(range(0, exp // 256)):
        ser.write(b'WRBK%04X' % (i + offset))
        res = ser.read(8)
        parcel = data[i*256:(i+1)*256]
        ser.write(parcel)
        checksum = np.uint8(ser.read(1)[0])
        
        
if __name__ == '__main__':
    main()

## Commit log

2023-10-18 Adding logism circuit
2023-10-21 Revising design
    [p2000t-ram-expansion-board.kicad_pcb, p2000t-ram-expansion-board.kicad_sch]
2023-10-22 Adding reverse polarity diode and silk screen comments
    [p2000t-ram-expansion-board.kicad_pcb, p2000t-ram-expansion-board.kicad_sch]
2023-10-23 Improving layout
    [p2000t-ram-expansion-board.kicad_pcb, p2000t-ram-expansion-board.kicad_sch]
2023-10-24 Adding GERBERS
    [p2000t-ram-expansion-board-B_Cu.gbr, p2000t-ram-expansion-board-B_Mask.gbr, p2000t-ram-expansion-board-B_Paste.gbr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]
2023-10-31 Adding ramtest script
    [p2000t-ram-expansion-board.kicad_sch]
2023-11-02 Revising PCB and updating code
    [p2000t-ram-expansion-board.kicad_pcb, p2000t-ram-expansion-board.kicad_sch]
2023-11-03 Polishing PCB
    [p2000t-ram-expansion-board-B_Cu.gbr, p2000t-ram-expansion-board-B_Mask.gbr, p2000t-ram-expansion-board-B_Paste.gbr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]
2023-11-12 Putting link to Github repo on PCB
    [p2000t-ram-expansion-board-B_Cu.gbr, p2000t-ram-expansion-board-B_Mask.gbr, p2000t-ram-expansion-board-B_Paste.gbr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]
2023-12-23 Board revision 3 (#2)
    * Adding 74HC245
    * Fixing connection
    * Revising board and fixing bugs
    * Updating README.md
    * Updating schematic
    * Replacing images
    [p2000t-ram-expansion-board-B_Cu.gbr, p2000t-ram-expansion-board-B_Mask.gbr, p2000t-ram-expansion-board-B_Paste.gbr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]
2024-01-06 Small fixes in schematic
    [p2000t-ram-expansion-board.kicad_sch]
2024-01-06 Adding SMD version of P2000T expansion board
    [p2000t-ram-expansion-board-smd-B_Cu.gbr, p2000t-ram-expansion-board-smd-B_Mask.gbr, p2000t-ram-expansion-board-smd-B_Paste.gbr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]
2024-03-28 Version 1056kb (#5)
    * Initial commit
    * Storing before routing
    * Adding gerbers and SVG
    * Adding support for 1056kb RAM expansion board to ramtester
    * Adding pictures of 1056kb expansion board
    * Adding SVG file
    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
    [p2000t-ram-expansion-board-1056kb-B_Cu.gbr, p2000t-ram-expansion-board-1056kb-B_Mask.gbr, p2000t-ram-expansion-board-1056kb-B_Paste.gbr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]
2024-05-20 Version 2080kb (#6)
    * Adding gerbers
    * Fixing bug in wiring
    * Fixing another bug 74HC74
    * Changing size
    * Revising PCBs
    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
    [p2000t-ram-expansion-board-1056kb-B_Cu.gbr, p2000t-ram-expansion-board-1056kb-B_Mask.gbr, p2000t-ram-expansion-board-1056kb-B_Paste.gbr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]
2024-06-02 Revision of RAM testing utility (#7)
    * Initial commit RAM tester rewrite
    * Revising ramtester
    * Small bugfixes
    * Expansion RAM test
    * Tweaking tests
    * Fixing small bugs in ramtest
    [main.c]
2024-08-31 Creating 128 KiB memory expansion using SMD components (#8)
    * Adding 128KiB SMD design
    * Changing silk screen
    * Saving schematic
    * Expanding README and ram testing routines
    * Revising board layout
    * Adding images
    [p2000t-ram-expansion-board-128kb-smd-B_Cu.gbr, p2000t-ram-expansion-board-128kb-smd-B_Mask.gbr, p2000t-ram-expansion-board-128kb-smd-B_Paste.gbr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]
2025-04-05 CPLD version of the 128 KiB memory expansion board (#9)
    * Initial commit CPLD version of RAM expansion board
    * Initial commit CPLD-based RAM expansion
    * Fixing CUPL script
    * Expanding README.md
    * Further revising README.md
    * Reintroducing picture
    * Fixing artifact level
    [p2000t-ram-expansion-board-128kb-smd-cpld-B_Cu.gbr, p2000t-ram-expansion-board-128kb-smd-cpld-B_Mask.gbr, p2000t-ram-expansion-board-128kb-smd-cpld-B_Paste.gbr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]
2025-06-21 Initial commit new board design
    [p2000t-ram-expansion-board-256kb-smd-cpld-B_Cu.gbr, p2000t-ram-expansion-board-256kb-smd-cpld-B_Mask.gbr, p2000t-ram-expansion-board-256kb-smd-cpld-B_Paste.gbr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]
2025-06-21 Expanding to 4 RAM chips
    [p2000t-ram-expansion-board-128kb-smd.kicad_pcb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]
2025-08-12 New 512 KiB SMD-CPLD board (#10)
    * Finalizing prototype
    * Adjusting CUPL
    * Fixing CUPL code for multi-ram
    * Expanding test suite
    * Further tuning ram tester
    * Implementing bank counting routine in RAM tester
    * Adding comments
    * Final tweaks to RAM tester
    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
    [p2000t-ram-expansion-board-128-512-smd-cpld-B_Cu.gbr, p2000t-ram-expansion-board-128-512-smd-cpld-B_Mask.gbr, p2000t-ram-expansion-board-128-512-smd-cpld-B_Pas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]

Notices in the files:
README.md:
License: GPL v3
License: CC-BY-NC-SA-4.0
